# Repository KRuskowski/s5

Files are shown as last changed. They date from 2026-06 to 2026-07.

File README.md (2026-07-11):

# einheit s5 — 5-Port Managed PoE Switch (product SKU: S501)

A 5-port gigabit **managed switch with PoE PSE**, built for an industrial
DIN-rail box. An Allwinner T113-S3 runs the Linux management plane and drives a
KSZ9477 switch ASIC over the kernel DSA subsystem; the ASIC does line-rate L2
switching, and two TPS23861 controllers source PoE on all five ports. The
simplest member of the `s1xx` Linux-switch family — `s100`'s software retargeted
onto cheaper hardware.

## Where it sits in the einheit switch line

| Project | CPU | ASIC | Framework | Role |
|---|---|---|---|---|
| `s` | RP2040 (bare metal) | KSZ8795 (SPI) | `cli/core` (C11) | Tiny embedded switch, serial CLI only |
| `s100` | Linux | KSZ9567 (DSA) | full `einheit-cli` | Linux switch CLI, 7-port |
| **`s5`** | **T113-S3 (Linux)** | **KSZ9477 (DSA)** | **`einheit-cli` + PoE** | **5-port managed PoE switch** |

s5 is essentially `s100`'s software (DSA switch adapter, einheit-cli) on cheaper
T113-S3 hardware with the 5-port KSZ9477, plus PoE PSE that `s100` doesn't have.

## Hardware — two boards

Split across a **core** board and a **power** board, joined by a coplanar
**Samtec PowerStrip** board-to-board interconnect (54 V PoE bus + MAIN_EN + logic;
no cable). Both on the SKiDL → KiCad netlist flow. **Both are essentially routed.**

### Core board — `hw/core` (4-layer, ~235 parts)
The switch + front I/O. Routed: ~2000 tracks / ~500 vias + copper zones.

| Block | Part |
|---|---|
| Management SoC | Allwinner **T113-S3** (eLQFP128, SiP 128 MB DDR3 — no external DDR routing, which is what makes 4-layer viable) |
| Switch ASIC | **KSZ9477S** (128-TQFP) — 5× GbE PHY + RGMII CPU port (port 6, MAC-to-MAC, no magnetics) |
| PoE PSE | 2× **TPS23861** (4-ch each) — all 5 ports |
| Magnetics + jacks | 5× PoE magnetics (LinkPP LPJG0926HENL) + RJ45 |
| Boot flash | **W25N02JW SPI NAND** (shared SPI0 bus) |
| Misc | watchdog (TPS3823), USB-C (FEL/debug), UART console |

Detail: `hw/core/README.md`, `hw/core/T113S3_PINMAP.md`, `hw/core/BOM_REAL_PARTS.md`.

### Power board — `hw/power` (~60 parts)
Industrial **24 V DC in → PoE + logic rails**. Routed mostly as copper pours.

- **24 V → LM5122 boost → 54 V** (VBUS_54V, the PoE bus)
- **TPS54560 buck → 5 V**, then LDO chain (3.3 / 2.5 / 1.2 / 1.8 / 0.9 V)
- High-current commutation loops laid out per `hw/power/CAP_PLACEMENT.md` (the
  boost output loop and buck input loop are the layout-critical ones).

## Software (`src/`, v0.1.0)

The einheit-cli stack on the **confd/engine management plane**:
- `switch_adapter.cc` — KSZ9477 via kernel DSA (ports directly from `s100`)
- `backend.cc` / `service.cc` — the management binary
- `poe.cc` — PoE port control
- `dsa.cc`, `sys.cc`, `util.cc` — DSA + platform glue

Builds `einheit_s5` (static) + `einheit_launch`. In-process transport, **no ZMQ**
(`EINHEIT_NO_ZMQ=ON`, like s100). Web UI (einheit-ui) planned — the T113-S3 has
the headroom.

### Rootfs
SPI NAND is too small for Debian → **Buildroot/OpenWrt minimal rootfs** (squashfs
in NAND). Different image pipeline from the firewall (T527 + eMMC + Debian).

## Status

- **Software:** v0.1.0, building. Switch adapter (KSZ9477/DSA), backend/service,
  PoE control; migrated to the confd/engine management plane.
- **Hardware:** core board **routed and DRC-clean**; power routed via copper
  pours (16 zones). 3D models aligned for the enclosure. Power board being
  redone (connector change moved the outline).
- **Power-tree audit (datasheet-verified):** all rails checked against
  datasheets — VDD-CORE/VDD-SYS 0.9 V, KSZ core 1.2 V / analog 2.5 V / I/O
  3.3 V, T113 VCC-DRAM fed by internal LDOB (pin 30 → 48/49), DZQ = 240 Ω,
  both PoE controllers' A3 address straps intentional, buck EN/FB/PG correct.
  **No board-killers.**
- **Resolved decisions:** ASIC = KSZ9477 · flash = SPI NAND (W25N02JW) ·
  board interconnect = Samtec PowerStrip (replaced the cable) · mounting M2.5.

### Open hardware items
1. **KSZ analog-supply ferrite — OPEN (must-fix before fab).** AVDDH (2.5 V,
   7 pins) and AVDDL (1.2 V, 9 pins) are fed straight from the regulators with
   no ferrite. Microchip HW Design Checklist DS00004151A §3.2 requires a series
   bead per analog rail (EVB uses 220 Ω 0603, low-DCR ≤0.05 Ω/1.2 V ≤0.1 Ω/
   2.5 V, ≥400/500 mA). Omitting eats 1000BASE-T compliance margin. Needs a
   net split (AVDDH/AVDDL onto their own post-ferrite nets) + 2 beads.

### Resolved by the datasheet audit
- **Power tree** — all rails datasheet-verified, no board-killers.
- **RGMII clock** — floating `RGMII_CLKIN_25M` (PG13) is a **non-issue**: the
  T113 EMAC self-generates the 125 MHz RGMII TXC internally (`ETCS_INT_GMII`);
  PG13 is an unused optional ext-clock input, not a 25 MHz ref. Both link
  clocks (TXC KSZ48↔T113·5, RXC KSZ57↔T113·121) are routed; SYNCLKO strap +
  pull-up correct. Cleanup only: rename the misnamed `_25M` net, give PG13 a
  defined level in the DTS. (RGMII **delay** — rgmii-id / KSZ pad-skew — is the
  software gotcha to handle at bring-up.)
- **T113 exposed pad → GND** — done (pad 129 = 6.4 mm EP, grounded).
- **T113 AVCC** — netlist correct at 1.8 V (pinmap doc was wrong, fixed);
  ferrite/RC filter recommended but optional (low-current analog).
- **Unused analog rails** (VCC-LVDS/HPVCC/TVOUT/TVIN) — safe to leave unpowered.

## v1 scope

A managed 5-port gigabit PoE switch configured via CLI (and later web UI):
- Per-port: enable/disable, link status, speed/duplex, statistics, **PoE control**
- VLAN: 802.1Q port-based and tagged
- Port mirroring, MAC table view, basic STP (if KSZ9477 + DSA expose it)

Out of scope for v1: LACP/bonding, advanced QoS, SNMP, routing (that's the
firewall's job).

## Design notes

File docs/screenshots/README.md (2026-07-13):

# s5 — 3D renders

3D views of the einheit **s5** core board and its DIN-rail enclosure, captured
2026-07-13 (KiCad 3D viewer + Fusion). Roughly board views first, enclosure last.

## screenshot_1
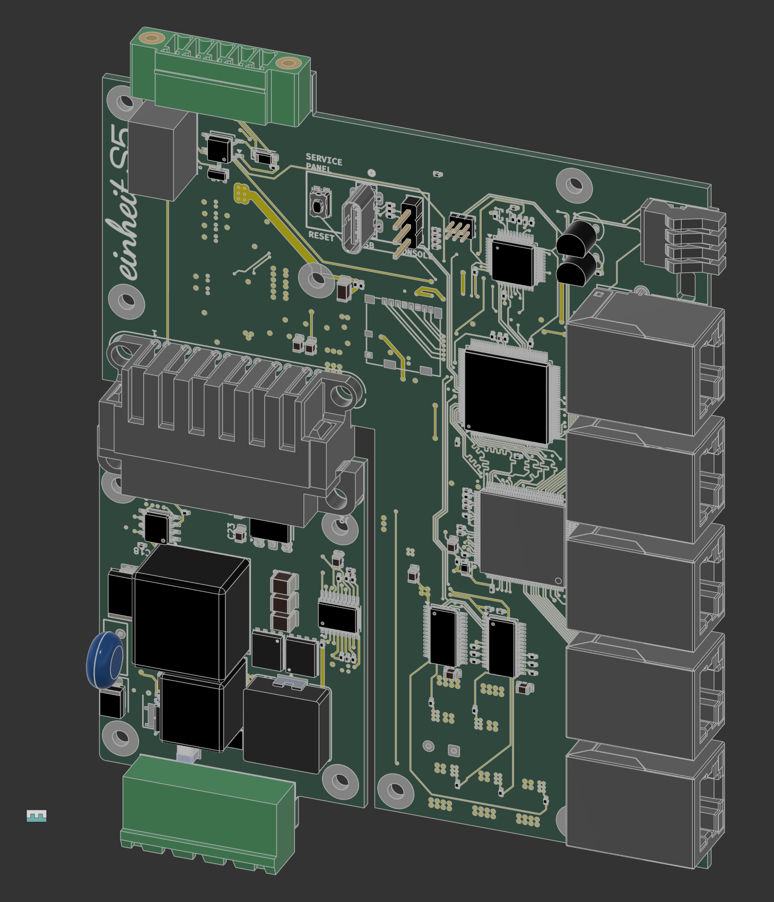
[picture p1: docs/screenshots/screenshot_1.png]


## screenshot_2
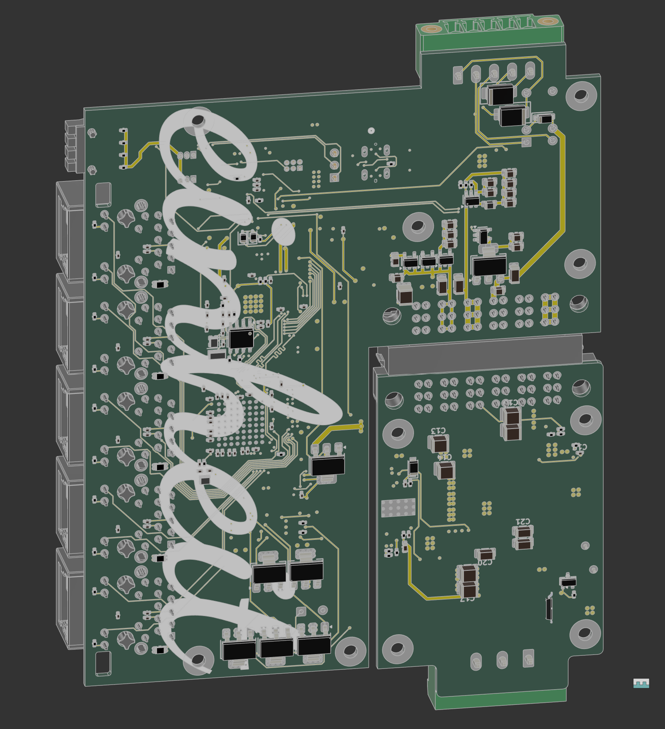
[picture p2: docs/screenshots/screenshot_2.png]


## screenshot_3
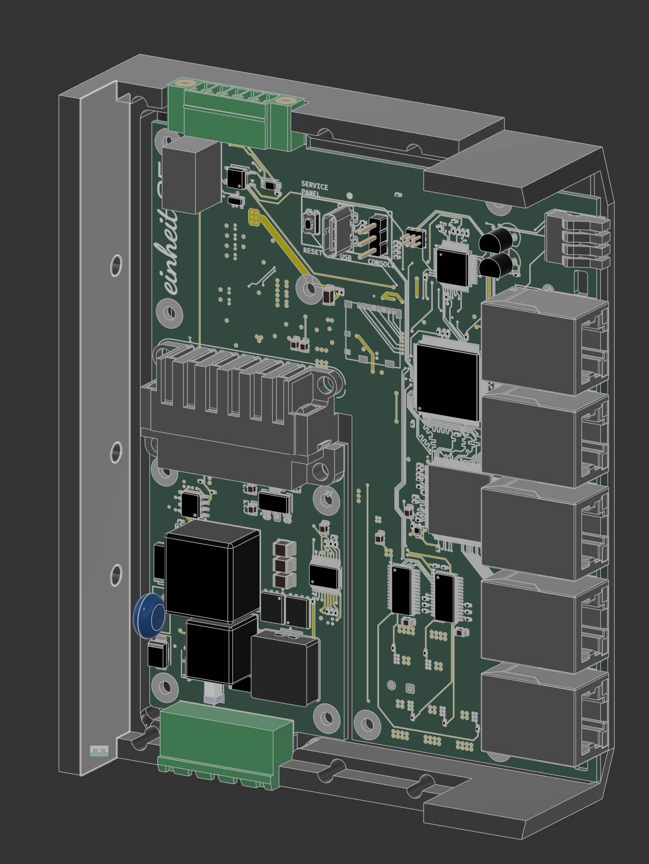
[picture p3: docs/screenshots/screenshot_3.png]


## screenshot_4
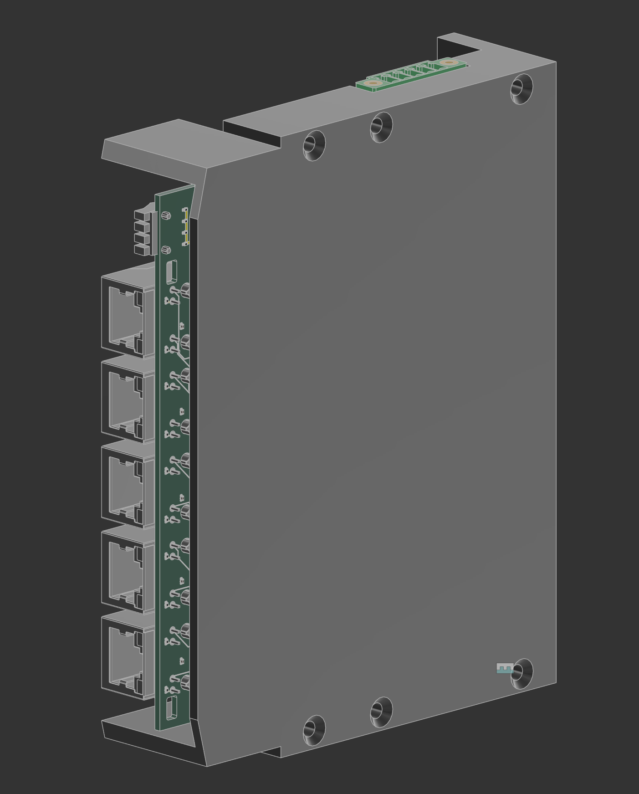
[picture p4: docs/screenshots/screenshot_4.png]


## screenshot_5
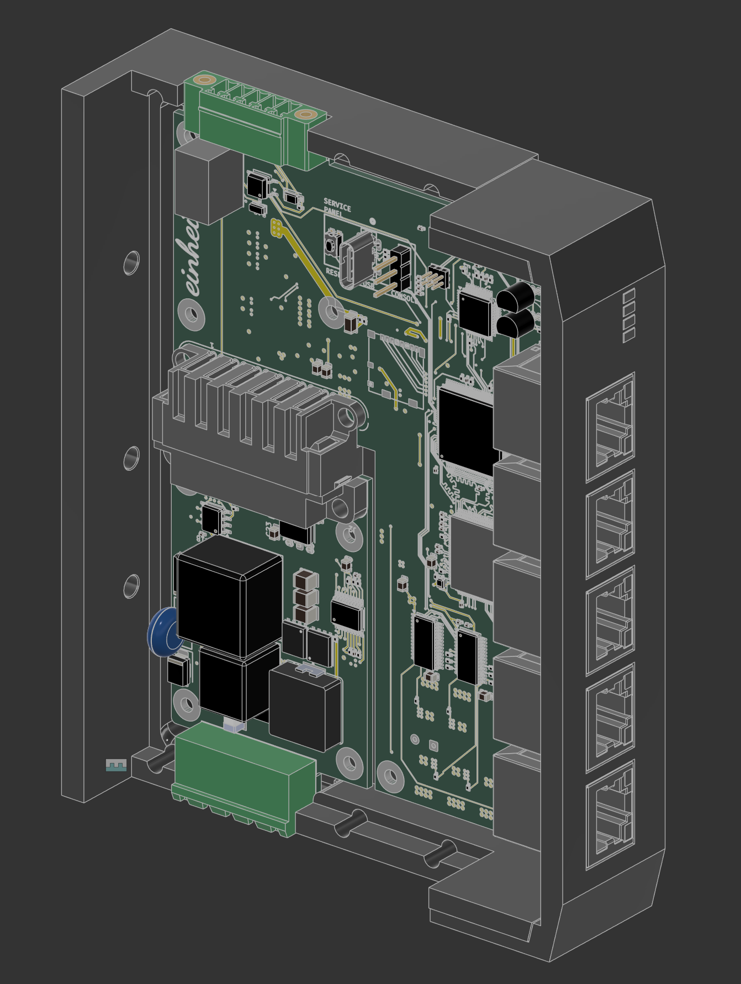
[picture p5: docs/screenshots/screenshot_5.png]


## screenshot_6
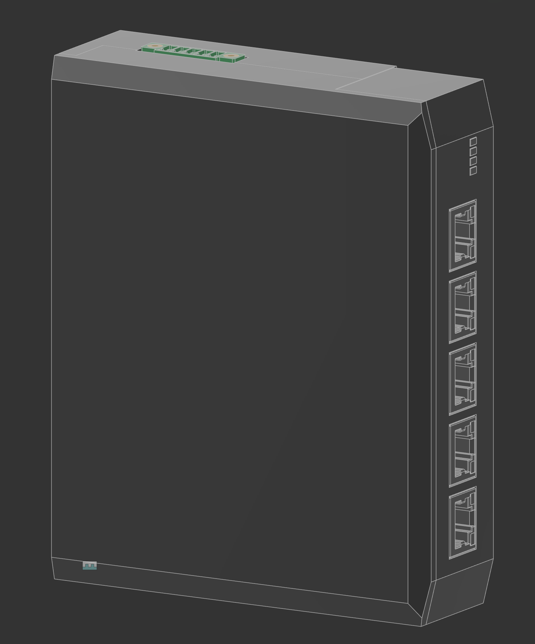
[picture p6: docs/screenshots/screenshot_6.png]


## screenshot_7
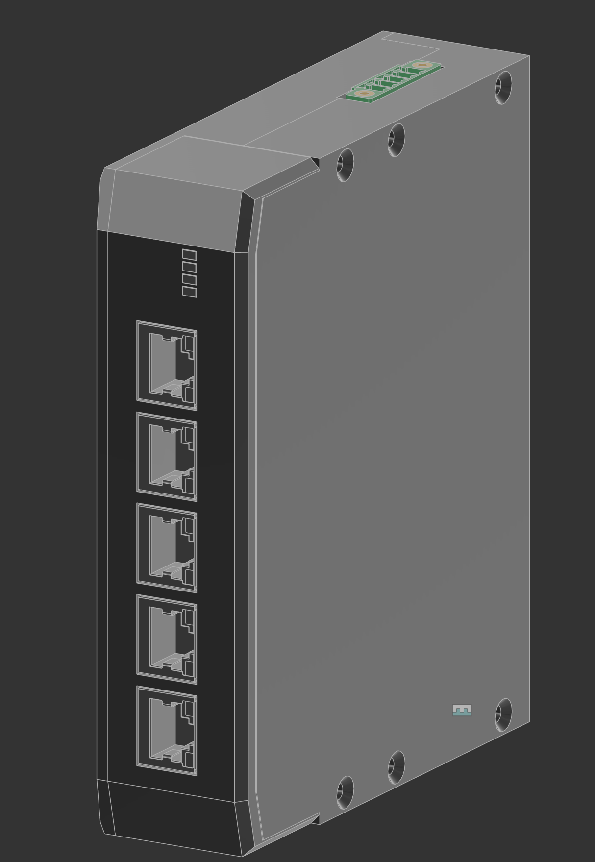
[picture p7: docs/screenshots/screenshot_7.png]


## screenshot_8
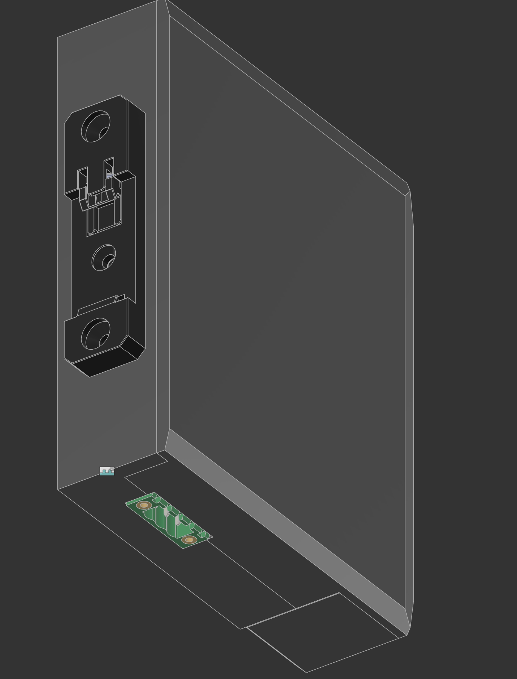
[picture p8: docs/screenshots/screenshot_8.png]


## screenshot_9
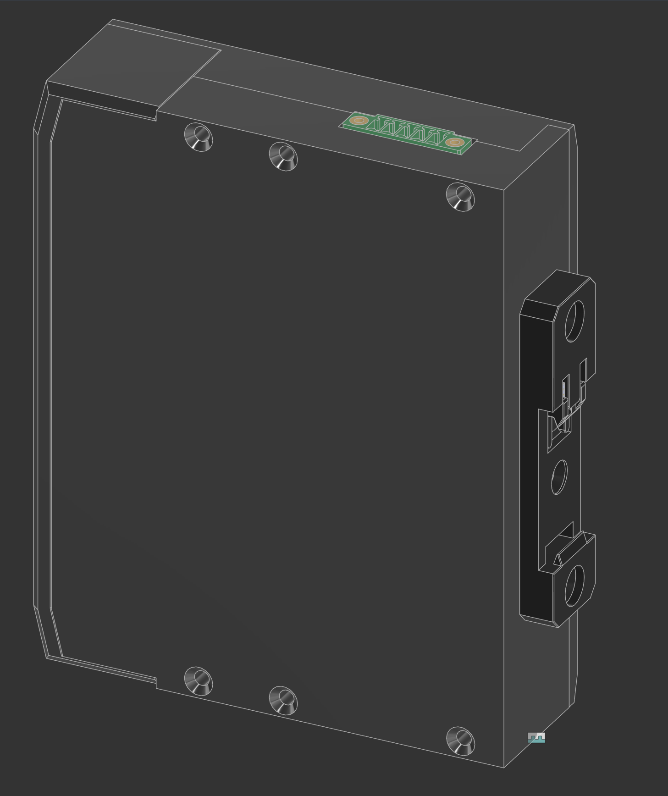
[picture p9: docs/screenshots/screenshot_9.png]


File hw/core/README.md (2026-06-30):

# s5 Hardware — 5-Port Managed Switch Board

KiCad + SKiDL hardware for the s5 (S501) switch.

## Generating the netlist

```sh
export KICAD_SYMBOL_DIR=/usr/share/kicad/symbols
export KICAD8_SYMBOL_DIR=/usr/share/kicad/symbols
python netlistscript          # writes netlist_s5.net
```

Import the result into KiCad: File -> Import -> Netlist.

## What's on the board

| Block | Part | Notes |
|---|---|---|
| Management SoC | **Allwinner T113-S3** (eLQFP128, SiP 128MB DDR3) | No external DRAM routing. Real pin numbers from datasheet v1.6 (see `T113S3_PINMAP.md`). |
| Switch ASIC | KSZ9477S (128-TQFP) | 5 copper GbE PHY ports + RGMII CPU port (port 6). Mainline DSA (`microchip,ksz9477`). |
| CPU-port link | T113 EMAC (RGMII, PG bank) -> KSZ port 6 | MAC-to-MAC, no magnetics, frees all 5 copper ports for users. |
| 5x GbE ports | Discrete GbE magnetics (YDS 30F-51NL) + plain RJ45 | Full 1000BASE-T (4 pairs/port). |
| PoE PSE | 2x TPS23861 (4ch each), all 5 ports | 48V DC in, N-FET + sense per port. |
| Power input | 48V DC -> TPS54560 buck (5V) | LDO chain: 3.3/2.5/1.2V (KSZ) + 0.9V buck (T113 core) + 1.8V LDO (DRAM). |
| Boot flash | W25Q128 SPI NOR (SOIC-8) | Shared SPI0 bus; flash CS on PC3, KSZ CS via GPIO. |
| Watchdog | TPS3823-33 (SOT-23-5) | RST -> T113 RESET, WDI from T113 GPIO. |
| Console | 3-pin UART header | T113 UART0 (PE2/PE3). |
| USB | USB-C (GCT USB4110) | Device mode for debug/FEL. |
| Stackup | **4-layer** | No external DDR3 = no high-speed signal layer needed. |

## Key design files

| File | Description |
|---|---|
| `netlistscript` | SKiDL connection script (the source of truth) |
| `netlist_s5.net` | Generated netlist (0 errors) |
| `T113S3_PINMAP.md` | T113-S3 pin map extracted from datasheet v1.6 |

## Open TODOs (marked in-script)

1. T113 eLQFP128 **exposed pad** -> GND is mandatory (only one
   dedicated GND pin: AGND=91). Add EP in the footprint.
2. RGMII CLKIN 25MHz reference source (KSZ SYNCLKO or crystal).
3. Unused analog rails (VCC-LVDS/HPVCC/TVOUT/TVIN) — confirm
   per datasheet §5.3 whether they may be left unpowered.
4. AVCC filtering (ferrite bead recommended per datasheet).
5. T113 package footprint (`eLQFP128_14x14x1.4mm`) — confirm
   or create.

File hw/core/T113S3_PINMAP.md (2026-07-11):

# T113-S3 Pin Map — verified from datasheet v1.6

Extracted from the Allwinner T113-S3 datasheet v1.6 (§4.2 Pin
Characteristics, §4.3 GPIO Multiplex Function). Package eLQFP128,
14×14×1.4 mm. Use these ball numbers for the netlist SoC block —
they are real, not placeholders.

**Critical:** only ONE dedicated ground pin (AGND = 91). The part
relies on the **exposed thermal pad = GND** for the main ground
return. The EP→GND connection is not optional.

## Power / ground / clock / reset

| Function | Signal | Ball# | Rail |
|---|---|---|---|
| Core | VDD-CORE0 / VDD-CORE1 | 116, 117 | 0.9 V (DCDC) |
| System | VDD-SYS0/1/2 | 46, 51, 81 | 3.3 V |
| IO | VCC-IO | 83 | 3.3 V |
| GPIO bank PE | VCC-PE | 34 | 3.3 V |
| GPIO bank PD | VCC-PD | 66 | 3.3 V |
| GPIO bank PG | VCC-PG | 128 | 3.3 V |
| PLL | VCC-PLL | 20 | 3.3 V |
| RTC | VCC-RTC | 26 | 3.3 V |
| DRAM I/O | VCC-DRAM0/1, VDD18-DRAM | 48, 49, 50 | 1.8 V |
| DRAM ZQ cal | DZQ | 47 | (240 Ω to GND) |
| Analog | AVCC | 89 | 1.8 V (analog; ferrite/RC filter recommended) |
| Internal LDO | LDO-IN / LDOA-OUT / LDOB-OUT | 29 / 28 / 30 | in 3.3 V, outs bypass |
| Ground | AGND | 91 | + **EP = GND** |
| 24 MHz osc | DXIN / DXOUT | 23 / 22 | DCXO |
| (ref clk out) | REFCLK-OUT | 21 | |
| 32.768 kHz | X32KIN / X32KOUT | 25 / 24 | RTC |
| Reset | RESET (I/OD) | 27 | VCC-RTC domain |
| Boot select | BOOT-SEL0 (PC4) / BOOT-SEL1 (PC5) | 17 / 16 | strap |
| NC | NC0 | 106 | leave open |

Unused analog/video rails (audio codec, TV out/in, LVDS) — HPVCC
(97), VCC-TVOUT (77), VCC-TVIN (107), VCC-LVDS (65): confirm
per-module whether they may be left unpowered when the module is
unused (most can; verify in §5.3 Recommended Operating Conditions).

## RGMII → KSZ9477 port 6 (PG group, mux Function4)

Full RGMII in one contiguous bank — this is the CPU/management link
that frees all 5 copper PHYs for users.

| RGMII signal | Pin | Ball# |
|---|---|---|
| RXCTL | PG0 | 120 |
| RXD0 | PG1 | 118 |
| RXD1 | PG2 | 119 |
| TXCK | PG3 | 121 |
| TXD0 | PG4 | 123 |
| TXD1 | PG5 | 122 |
| TXD2 | PG6 | 1 |
| TXD3 | PG7 | 2 |
| RXD2 | PG8 | 3 |
| RXD3 | PG9 | 4 |
| RXCK | PG10 | 5 |
| TXCTL | PG12 | 124 |
| CLKIN (RX clk in) | PG13 | 125 |
| MDC | PG14 | 126 |
| MDIO | PG15 | 127 |

(RMII is also available on this bank if a 100 M link is ever
preferred: PG0=CRS-DV, PG1/2=RXD0/1, PG3=TXCK, PG4/5=TXD0/1,
PG12=TXEN, PG13=RXER.)

## SPI0 → KSZ9477 management + boot flash (PC group, Function2)

| SPI0 signal | Pin | Ball# |
|---|---|---|
| CLK | PC2 | 19 |
| CS0 | PC3 | 18 |
| MOSI | PC4 | 17 |
| MISO | PC5 | 16 |
| WP | PC6 | 15 |
| HOLD | PC7 | 14 |

Shared bus: SPI0-CS0 (PC3) → boot flash. The KSZ9477 needs its own
chip-select — assign a spare GPIO (e.g. a PB or PD pin) as KSZ_CS,
same pattern as v3.

## TWI0 → TPS23861 PoE controller (PB group, Function4)

| TWI0 signal | Pin | Ball# |
|---|---|---|
| TWI0-SDA | PB2 | 86 |
| TWI0-SCK | PB3 | 85 |

## UART0 debug console (PE group, Function6)

| UART0 signal | Pin | Ball# |
|---|---|---|
| UART0-TX | PE2 | 35 |
| UART0-RX | PE3 | 33 |

## Notes for the netlist

- Footprint: reuse v3's `LQFP-128_14x14mm_P0.4mm` + add the exposed
  pad (EP → GND). Confirm body/pitch matches eLQFP128 from §7.2.
- Power tree changes from v4 (H3): drop the external DDR3 (+1.5 V
  rail) and the SY8106A DVFS buck. The T113 core is a 0.9 V DCDC
  (VDD-CORE 116/117); add a 1.8 V rail for VDD18-DRAM; reuse v4's
  3.3 V for the SYS/IO/PE/PD/PG/PLL/RTC domains.
- Source: Allwinner T113-S3 datasheet v1.6, §4.2 / §4.3.

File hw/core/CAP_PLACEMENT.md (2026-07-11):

# s5-core — decoupling / bulk cap placement guide

Where every capacitor on `s5.kicad_pcb` goes, **named**. Refs match
`netlist_s5.net` (regenerate before cross-checking: `python netlistscript`).

**The one rule:** a *decoupling* cap goes **next to the power pin it serves**,
one per pin, shortest via to the plane — not clustered at the regulator. Groups
below with many caps on one rail = **one per pin of that IC.** *Bulk* caps (the
bigger 10 µF) go at the **rail source** (converter output / interconnect blade).

Cap ref ranges are from the netlist; the KSZ-vs-T113 split on the shared 3.3 V
rail is by creation order (KSZ section builds before T113).

---

## 1. Interconnect entry — at the J9 PowerStrip blades

| Rail | Caps | Value | Place |
|---|---|---|---|
| **VBUS_54V** | **C1** | 10 µF / 1210 **≥100 V** | J9 blade 1. ⚠️ must be a 100 V part |
| VIN_24V | C2, C10 | 10 µF | J9 blade 3 |
| VDD_5V | C3, C5, C11 | 10/22 µF | J9 blade 4 / 5 V input |
| VDD_3V3 (entry) | C4, C12 | 10 µF | J9 blade 5 |

## 2. Point-of-load converters — in/out caps tight to each

| Converter | Caps | Place |
|---|---|---|
| 0.9 V buck **U11** (TLV62569) | **C6, C7** (22 µF out) · **C15, C90** (10 µF) + inductor | all four sit AT U11 (top-right strip, X≈186-192 / Y≈72), NOT at the T113. Tightest loop — Cin at VIN, SW→L→Cout small |
| U3 AP2112K-2.5 (KSZ 2.5 V) | **C13** (10 µF out) | at U3 |
| U4 AP2112K-1.2 (KSZ+T113 1.2 V) | **C14** (10 µF out) | at U4 |
| AP2112K-1.8 (T113 1.8 V) | **C8, C9, C16** (10 µF) | at the LDO |
| 3.3 V rail bulk | **C91** (10 µF) | bulk on VDD_3V3 near the LDO cluster (U3/U4/U12, X≈171/Y≈87) / where VDD_3V3 lands from J9 — not pin-critical |
| microSD VDD | **C95** (100 nF) | at **J8** microSD VDD pin (X≈175/Y≈104) — SD-card 3.3 V decoupling |
| flash VCC | **C96** (100 nF) | at **U8** W25N02 flash pin 8 VCC (X≈162/Y≈124) — tight |

## 3. KSZ9477S (U1) — one cap per power pin

| Rail | Caps | Value | Place |
|---|---|---|---|
| **VDD_1V2** (core) | **C26–C45** (20) | 100 nF | **one next to each KSZ 1.2 V pin** — the big one |
| VDD_2V5 (analog) | **C17–C25** (9) | 100 nF | one per KSZ 2.5 V (AVDDH/VDDHS) pin |
| VDD_3V3 (I/O) | **C46, C47, C48** | 100 nF | one per KSZ VDDIO pin |
| 25 MHz crystal | **C49, C50** | 15 pF | XI / XO legs, tight to the crystal |
| Reset RC | **C51** | 10 µF | at the KSZ reset pin |

## 4. T113-S3 (U7) — one cap per power pin

| Rail | Caps | Value | Place |
|---|---|---|---|
| **VDD_3V3** (I/O banks) | **C68–C79** (12) | 100 nF | one per T113 VCC-IO 3.3 V pin |
| **VDD_CORE 0.9 V** (VDD-CORE + VDD-SYS) | **C80–C85** (6) | 100 nF | one per core pin. ⚠️ VDD-SYS is 0.9 V, not 3.3 |
| VDD_1V8 (PLL/RTC/AVCC/DDR-ctrl) | **C86–C89** (4) | 100 nF | one per 1.8 V analog pin. ⚠️ not 3.3 V |
| Internal LDO out | **C66, C67** | 1 µF | at T113 LDO-A / LDO-B output pins |
| 24 MHz crystal | **C92, C93** | 18 pF | XIN / XOUT, tight to the crystal |
| Reset | **C94** | 100 nF | at the T113 reset pin |

## 5. TPS23861 PoE PSE (U11 / U12)

| Rail | Caps | Place |
|---|---|---|
| **VDD_3V3_PSE** (vpse33, always-on) | **C62, C64, C100, C101** | 2 per controller at the VDD pin (1) |
| **VBUS_54V** (VPWR) | **C63, C65** (100 nF) | near each controller's VPWR pin (28). ⚠️ 100 nF but on the 54 V rail — must be **≥100 V** parts |

## 6. Standby / PoE-logic 3.3 V (always-on)

| Rail | Caps | Place |
|---|---|---|
| VDD_3V3_SB | **C97–C99, C102–C105, C107–C109** (10) | at the standby 3V3 LDO (U18/U20) + the PoE-logic loads |

## 7. RJ45 MagJacks (J2–J6) — center-tap caps

| Port | Caps | Place |
|---|---|---|
| P1 | C52, C53 | at MagJack 1 center-tap pins (Bob-Smith) |
| P2 | C54, C55 | at MagJack 2 |
| P3 | C56, C57 | at MagJack 3 |
| P4 | C58, C59 | at MagJack 4 |
| P5 | C60, C61 | at MagJack 5 |

## 8. Misc

| Cap | Net | Place |
|---|---|---|
| C106 | MCU_NRST | watchdog / reset RC |
| C110 | PE | earth Y-cap (protective earth) |

---

## Priority order when placing

1. **0.9 V buck loop** (C6/C7/C15 + L) — fires or fails EMI if loose.
2. **VBUS_54V bulk C1** — 100 V part, right at the blade.
3. **KSZ 1.2 V (C26–C45)** and **T113 core (C80–C85) / 1.8 V (C86–C89)** — one per pin, shortest vias.
4. Everything else (2.5 V, 3.3 V decoupling, magjack CT caps) — one per pin, less critical.

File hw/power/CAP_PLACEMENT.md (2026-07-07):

# s5-power — decoupling / bulk cap placement guide

Which component each capacitor must sit next to when laying out `power.kicad_pcb`.
Refs match `netlistscript` (regenerate before cross-checking: `netlist_s5power.net`).

**Two things that bite:**

- **Several caps share the `VIN_24V` net but belong in different places** — do not cluster them. C4 bypasses the boost controller, C13/C14 feed the boost power stage, C17/C18 feed the buck input. Same net, three physical locations, each next to its own consumer.
- **The loop caps (⚠) are the ones that cause fires / fail conducted-EMI if placed loosely.** Place them first and tightest; everything else is secondary.

## ⚠ Critical high-current loops — tightest, place first

| Cap | Value | Place across / next to |
|-----|---|---|
| **C10, C11, C12** | 10µF/100V | Boost **output** loop: across **Q3 (QH) drain pins 5–8 (VBUS_54V)** and **Q2 (QL) source pins 1–3 (PGND)**. This is the boost commutation loop — keep the Cout→Q3→Q2 area physically tiny. |
| **C17, C18** | 2.2µF | Buck **input** loop: hug **U2 pin 2 (VIN)** and **U2 pin 7 + EP (pin 9, GND)**, forming a tight loop with catch diode **D3**. Single most layout-sensitive cap on the buck. |
| **C13, C14** | 22µF/63V | Boost power-stage **input reservoir** (feeds the inductor). Straddle VIN_24V→GND right at **RS pin 1** (24V side of the sense resistor, = L1's input end); ground into the **PGND pour by Q2 (QL) source**. Closes the loop C13/14→RS→L1→QL→PGND. NOT at the LM5122 chip (that's C4) and NOT at the board entry (that's C2/C3). Boost input current is continuous, so "near RS/L1, grounded to PGND" is enough — not as critical as the C10–C12 output loop. |

## LM5122 boost controller (U1) — housekeeping, hug the pin

| Cap | Value | Near |
|-----|---|---|
| **C4** | 1µF | U1 **pin 5 (VIN)** → return to pin 9 (AGND) |
| **C5** | 4.7µF | U1 **pin 17 (VCC)** → AGND |
| **C9** | 100nF | Bootstrap: U1 **pin 20 (BST)** → **pin 18 (SW)**; keep the loop to the Q2/Q3 gate area short |
| **C6** | 100nF | U1 **pin 7 (SS)** |
| **C7** | 10nF | U1 **pin 11 (COMP)** |
| **C8** | 100pF | Across U1 **pins 3/4 (CSN/CSP)** — put it right at the pins; route it and the two 100R sense resistors as a Kelvin pair back across **RS**. |

## TPS54560 buck (U2)

| Cap | Value | Near |
|-----|---|---|
| **C15** | 100nF | Bootstrap: U2 **pin 1 (BOOT)** → **pin 8 (PH)** |
| **C16** | 15nF | U2 **pin 6 (COMP)** |
| **C19, C20** | 22µF | Buck **output**: at **L2 output (VDD_5V)**; return near U2 GND |

## Input front-end & LDO

| Cap | Value | Near |
|-----|---|---|
| **C1** | 10µF | **Before** ferrite FB1 (VIN_PROT) — by Q1 drain |
| **C2** | 10µF | **After** ferrite FB1 (VIN_24V) |
| **C3** | 100µF | Bulk at input — near FB1 output / J1 |
| **C21** | 10µF | AMS1117 **U3 pin 2 (VO / VDD_3V3)** output |

## General rule

Every GND-return cap wants its own stitching via straight down to the ground plane, right at the cap pad — never a long shared ground trace back to the IC. Loop-critical caps go on the same layer as their IC, hugging the pin. Bulk caps (C3, C10–C12) may sit a little further out.

## Open item

**U3 (AMS1117) has no dedicated input cap** on pin 3 (VI / VDD_5V) — it currently relies on the buck output caps C19/C20 upstream. If U3 lands any distance from them, add a 1µF at U3 pin 3.

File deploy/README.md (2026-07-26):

# On-device deployment

What has to be installed on an s5 box beyond the binary itself, and why.
Dev-board specifics for the T153 Lume live in `t153-dev-setup.md`.

## Files

| Source | Destination | Mode | Purpose |
|---|---|---|---|
| `build/einheit_s5` | `/usr/local/bin/einheit_s5` | 755 | CLI + management plane |
| `build/einheit-launch` | `/usr/local/bin/cli` | 4755 root:root | setuid launcher (the privilege boundary) |
| `deploy/einheit-s5-boot.service` | `/etc/systemd/system/` | 644 | boot-restore (systemd images) |
| `deploy/S39einheit-s5` | `/etc/init.d/S39einheit-s5` | 755 | boot-restore (BusyBox init — the production image) |
| `deploy/factory.conf.example` | `/etc/einheit/s5/factory.conf` | 644 | shipped defaults for `load factory` |

Durable state (running config, commit history, audit log, saved
configurations, the configure-mode lock) lives in `/var/lib/einheit/s5`,
created on first run. It must be on a writable, persistent filesystem —
on the production SPI-NAND image that means a writable overlay, not
squashfs.

`/var/run/einheit` holds **generated apply artifacts** — the dnsmasq
configuration, the LLDP daemon's configuration, the mDNS repeater's
argument list, the DHCP lease database, and one marker file per service
recording whether the configuration wants it. All of it is rebuilt from
the committed configuration on every commit and every boot, so a tmpfs
is correct and a wipe is harmless. Nothing here is operator-editable and
nothing here needs to survive a reboot.

## Packages the image must carry

Phase 2 turns several features into "a daemon plus a generated config".
The backend **fails the commit** when the binary is absent rather than
reporting success and doing nothing, so a missing package is a feature
the operator cannot turn on — loudly, which is the intent. What the
image needs:

| Package | Needed by | Absent means |
|---|---|---|
| `mstpd` (+ `mstpctl`, `/sbin/bridge-stp`) | RSTP (WP1.2) | **the box cannot complete its first boot** — `stp.mode rstp` is in the shipped factory configuration |
| `dnsmasq` | DHCP server + DNS forwarder (WP2.3) | `vlans.<vid>.dhcp.*` and `dns.serve` are refused at commit |
| `mdns-repeater` | mDNS reflection (WP2.4) | `mdns.enabled` is refused at commit |
| busybox `ntpd` applet (with `-l`) | time client and server (WP2.5) | `ntp.server` is refused at commit |
| `iproute2` (`ip`, `bridge`) | fabric, VLANs, SVIs, routes | nothing works |
| `ethtool` | port speed/duplex/flow control | those paths fail; the rest is fine |

Buildroot has packages for all of these (`BR2_PACKAGE_MSTPD`,
`BR2_PACKAGE_DNSMASQ`, `BR2_PACKAGE_MDNS_REPEATER`,
`BR2_BUSYBOX_...NTPD`). mstpd is **not** in Debian trixie, so the test
VM builds it from `github.com/mstpd/mstpd` — see the note in
`test/vm_prep.sh`'s companion documentation below.

The LLDP daemon is not a package: it is `einheit_s5 --lldp-daemon`, the
same binary in another mode (see `include/einheit/s5/lldp.h` for why we
own the implementation rather than packaging lldpd). It is started by a
commit and should also be started at boot, after `--apply-boot` has
generated its configuration.

### mstpd and the kernel's user-space STP handshake

`stp.mode rstp` sets `/sys/class/net/br0/bridge/stp_state`, which makes
the kernel run `/sbin/bridge-stp br0 start`. That helper — shipped with
mstpd — starts the daemon and registers the bridge, and only if it
succeeds does the kernel settle on `BR_USER_STP` (stp_state **2**). If
the helper is missing or fails, the kernel silently falls back to its
own 802.1D (stp_state 1), which is not what the operator asked for, so
the backend verifies the resulting state and fails the commit otherwise.
`/etc/bridge-stp.conf` needs no entry: with `MSTP_BRIDGES` empty, mstpd
manages every bridge, which is what we want on a box with one.

## Boot-restore

Nothing else re-applies committed configuration when the box comes back.
Install one of the two units and the box boots into its own
configuration; install neither and every reboot is effectively a factory
reset with the operator's intent left behind in `show commits`.

```sh
# systemd
systemctl enable einheit-s5-boot.service

# BusyBox init — S39 runs immediately before Buildroot's S40network, so
# br0 and the enslaved ports exist before anything addresses br0.
chmod 755 /etc/init.d/S39einheit-s5
```

Both run `einheit_s5 --apply-boot`, which:

1. builds the switch fabric — `br0` with `vlan_filtering=1`, `lan1..lan4`
   enslaved, `lan5` left routed as the uplink, the DSA conduit up —
   idempotently;
2. re-applies the newest commit's configuration through the same
   `S5Backend::Apply` a `commit` uses;
3. reconciles: intent wins for every path the commit carried, the box
   fills in the rest.

An unconfirmed `commit confirmed` window is **reverted**, not carried
forward: the oneshot has no live timer to fire the auto-revert later, so
carrying the window would quietly make an unconfirmed configuration
permanent. Boot is the confirm deadline.

Both are ordered **before sshd and getty**, not merely before
`multi-user.target`: ordering against a target does not order against the
units pulled into it, so without naming sshd explicitly systemd starts it
concurrently and an operator can log into a switch that has no bridge and
no VLANs yet. On BusyBox init the `S39` prefix gives the same guarantee
against Buildroot's `S50sshd`.

The systemd unit is deliberately **not** ordered before
`network-pre.target`. That reads like the right thing ("before anything
touches the interfaces") and is a trap: `network-pre` is a sysinit-phase
target while the unit is `WantedBy=multi-user.target`, which systemd
reaches only after sysinit — an ordering cycle. systemd breaks a cycle by
deleting a job, and it picked this unit on 2 of 50 power cuts during
Phase 0 testing, booting the box with no fabric and no restored config,
silently. If boot-restore ever appears to be skipped, that is the first
thing to check:

```sh
journalctl -b | grep -E "ordering cycle|deleted to break"
systemd-analyze verify /etc/systemd/system/einheit-s5-boot.service
```

Exit code 0 means restored (or "nothing committed yet"); non-zero means
the fabric or the apply failed, and the box is running whatever it
powered on with. Check `journalctl -u einheit-s5-boot` or the console,
then `show fabric` and `show commits`.

There is deliberately no retry: re-running a half-applied hardware write
is how a bad boot becomes a bad box.

### Ordering caveat

DSA user ports appear asynchronously as the switch driver probes. If
`--apply-boot` runs before a port exists, the fabric bootstrap skips it
and reports it as absent rather than failing — `show fabric` names the
absent ports, and the next commit enslaves them. On an image where this
races, order the unit after the driver's udev settle.

## Verifying a deployment

```
show fabric        # bridge up, vlan_filtering yes, 4 members enslaved
show commits       # history survived the reboot
show config        # running config matches the newest commit
show status        # lock_holder=<none> on a fresh boot
```

`test/vm_integration.sh` drives all of this over ssh against a
disposable target, including power-cycling the fabric behind confd's
back and re-running `--apply-boot`.

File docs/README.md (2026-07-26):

# einheit s5 — operator documentation

Two kinds of pages, with different rules:

- **`reference.md` — generated, never hand-edited.** Produced by `einheit_s5 --dump-docs` from the schema and command tree the binary actually runs, so it cannot disagree with the product. A ctest diffs the checked-in file against the binary's output: adding a config path or verb without regenerating fails the build (`./build/einheit_s5 --dump-docs > docs/reference.md`). To fix wording here, edit the schema help strings / command specs and regenerate — that same text is what `?`, `show schema` and the hint system display.
- **`guide/` — hand-written.** The narrative that cannot be generated: what the configuration model is, how commit-confirmed saves you, how VLANs are meant to be used. Review passes and corrections belong here (and in the schema help strings via the rule above).
  - [`guide/configuration.md`](guide/configuration.md) — candidate/commit, rollback, saved configurations, boot behaviour.
  - [`guide/switching.md`](guide/switching.md) — the fabric, VLANs, ports, spanning tree, LLDP, MAC table, multicast, PoE.
  - [`guide/services.md`](guide/services.md) — SVIs, routing, DHCP, DNS, mDNS reflection, time, and what a service that is down looks like.

Every feature lands with both halves: regenerated reference plus its guide section (workspace acceptance criteria enforce this).

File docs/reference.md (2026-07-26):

# einheit S5 — CLI Reference

Generated by `--dump-docs` from the running binary (product `s5`, version 0.2.1). **Do not edit** — wording fixes belong in the schema help strings and command specs; regenerate and commit.

## Configuration paths

Set inside a `configure` session: `set <path> <value>`, `delete <path>`, then `commit`. `<name>` marks a key you choose (a port, an interface, a VLAN id).

| Path | Type | Default | Description |
|---|---|---|---|
| `dns.local_domain` | string | — | Domain for names the switch serves itself |
| `dns.primary` | ip | — | Primary DNS nameserver |
| `dns.secondary` | ip | — | Secondary DNS nameserver |
| `dns.serve` | boolean | false | Answer DNS queries from clients, forwarding what we do not know |
| `hostname` | string | — | Switch hostname |
| `igmp_snooping.enabled` | boolean | true | Prune multicast to ports that asked for it |
| `igmp_snooping.querier` | boolean | false | Send IGMP queries (needed with no router on the L2) |
| `interfaces.<name>.address` | cidr | — | Static address + prefix |
| `interfaces.<name>.dhcp` | boolean | false | Acquire the address via DHCP instead |
| `interfaces.<name>.gateway` | ip | — | Default gateway reached through this interface |
| `lldp.enabled` | boolean | true | Announce this switch to its neighbours, and record theirs |
| `lldp.port.<name>.enabled` | boolean | true | Run LLDP on this port |
| `lldp.tx_interval` | integer [5..3600] | 30 | Seconds between announcements |
| `mac.aging_time` | integer [10..1000000] | 300 | Seconds before a learned MAC is forgotten |
| `mac.static.<name>.port` | string | — | Port the static entry points at |
| `mac.static.<name>.vlan` | integer [1..4094] | 1 | VLAN the static entry belongs to |
| `mdns.enabled` | boolean | false | Repeat mDNS between VLANs so discovery crosses them |
| `mdns.reflect.<name>` | boolean | — | Include this VLAN in mDNS reflection |
| `ntp.serve` | boolean | false | Also answer time queries from clients on this network |
| `ntp.server` | string | — | NTP server hostname or IP |
| `poe.<name>.enabled` | boolean | true | PoE power delivery on this port (1-5) |
| `poe.<name>.power_limit_mw` | integer [0..30000] | — | Per-port power limit in milliwatts |
| `ports.<name>.duplex` | enum {auto, half, full} | auto | Duplex mode, or auto-negotiate |
| `ports.<name>.enabled` | boolean | true | Administrative port state (lan1..lan5, wan) |
| `ports.<name>.flow_control` | boolean | false | 802.3x pause frames |
| `ports.<name>.mtu` | integer [1280..9216] | 1500 | Maximum transmission unit |
| `ports.<name>.speed` | enum {auto, 10, 100, 1000} | auto | Link speed in Mbit/s, or auto-negotiate |
| `ports.<name>.stp.bpdu_guard` | boolean | false | Block this port if another switch sends spanning-tree into it |
| `ports.<name>.stp.cost` | integer [0..200000000] | 0 | Spanning-tree path cost; 0 derives it from link speed |
| `ports.<name>.stp.edge` | boolean | false | Access port: skip the listening delay and forward at once |
| `ports.<name>.stp.priority` | enum {0, 16, 32, 48, 64, 80, 96, 112, 128, 144, 160, 176, 192, 208, 224, 240} | 128 | Port priority; breaks ties between equal-cost paths to the root |
| `ports.<name>.vlan.<name>` | enum {tagged, untagged, pvid, untagged-pvid} | — | 802.1Q membership mode for this VID |
| `routing.enabled` | boolean | false | Forward traffic between VLANs and to the uplink |
| `routing.static.<name>.prefix` | cidr | — | Destination network; 0.0.0.0/0 is the default route |
| `routing.static.<name>.via` | ip | — | Next-hop address |
| `stp.forward_delay` | integer [4..30] | 15 | Seconds a port waits before forwarding (classic mode only) |
| `stp.hello` | integer [1..10] | 2 | Seconds between spanning-tree messages from the root |
| `stp.max_age` | integer [6..40] | 20 | Seconds before a silent neighbour is assumed gone |
| `stp.mode` | enum {rstp, stp, off} | rstp | Loop protection: rapid spanning tree, classic, or none |
| `stp.priority` | enum {0, 4096, 8192, 12288, 16384, 20480, 24576, 28672, 32768, 36864, 40960, 45056, 49152, 53248, 57344, 61440} | 32768 | Bridge priority; the lowest value on the network becomes the root |
| `vlans.<name>.address` | cidr | — | Switch address in this VLAN; giving one makes it routable |
| `vlans.<name>.dhcp.dns` | ip | — | Nameserver told to clients; defaults to the switch itself |
| `vlans.<name>.dhcp.enabled` | boolean | false | Hand out addresses to clients in this VLAN |
| `vlans.<name>.dhcp.gateway` | ip | — | Router told to clients; defaults to the switch itself |
| `vlans.<name>.dhcp.lease_time` | integer [2..10080] | 720 | Minutes a client keeps its address |
| `vlans.<name>.dhcp.range_end` | ip | — | Last address handed out |
| `vlans.<name>.dhcp.range_start` | ip | — | First address handed out |
| `vlans.<name>.dhcp.static.<name>.ip` | ip | — | Address always given to this MAC |
| `vlans.<name>.name` | string | — | What this VLAN is for, e.g. office or guest |

## Configuration lifecycle commands

| Command | Role | Description |
|---|---|---|
| `commit` | admin | Apply the candidate configuration |
| `commit confirmed <minutes>` | admin | Apply, then auto-revert unless confirmed in time |
| `configure` | admin | Enter configure mode and open a candidate session |
| `configure force` | admin | Take configure mode from another session, discarding its candidate |
| `confirm` | admin | Confirm a pending commit-confirmed (cancel auto-revert) |
| `delete <path>` | admin | Remove a candidate-config value at a schema path |
| `load factory` | admin | Load the shipped factory defaults into the candidate (commit to complete a factory reset) |
| `load merge <name>` | admin | Merge a saved configuration into the candidate |
| `load replace <name>` | admin | Replace the candidate with a saved configuration |
| `rollback candidate` | admin | Discard the candidate session |
| `rollback previous` | admin | Roll back to the previous commit |
| `rollback rescue` | admin | Restore the saved rescue configuration and commit it |
| `rollback to <id>` | admin | Re-apply a specific committed revision |
| `save <name>` | admin | Save the running configuration to a named file |
| `set <path> <value>` | admin | Set a candidate-config value at a schema path |
| `show commit <id>` | any | Show a single commit by id |
| `show commits` | any | List commit history |
| `show config [prefix]` | any | Show running configuration (optional prefix) |
| `show configs` | any | List saved configuration files |
| `show diff` | any | Show uncommitted candidate changes vs running (Junos: show \| compare) |
| `show schema` | any | List every configurable path with type + help |

## Show commands

| Command | Role | Description |
|---|---|---|
| `show counters [port]` | any | Show port counters |
| `show dhcp leases` | any | Show which clients hold which addresses |
| `show dhcp server` | any | Show the DHCP pools being served, and their usage |
| `show dns` | any | Show DNS servers |
| `show env` | any | Show terminal caps, active theme, aliases, target, session |
| `show fabric` | any | Show the switch fabric (bridge, members, conduit) |
| `show igmp-snooping` | any | Show multicast snooping state and groups |
| `show interfaces [port]` | any | Show port status |
| `show interfaces detail [port]` | any | Show configured vs negotiated link parameters and counters |
| `show ip` | any | Show IP addresses |
| `show log [lines]` | any | Show syslog |
| `show mac-table [port]` | any | Show the MAC table (static and learned) |
| `show neighbors [port]` | any | Show LLDP neighbours heard on each port |
| `show ntp` | any | Show NTP status |
| `show poe [port]` | any | Show PoE status |
| `show route` | any | Show the routing table and whether forwarding is on |
| `show spanning-tree` | any | Show the spanning tree: root, and each port's role and state |
| `show spanning-tree statistics [port]` | any | Show per-port BPDU counters and state transitions |
| `show status` | any | Show config-plane status: commits, session, edit lock, pending commit-confirmed |
| `show system` | any | Show system info |
| `show system boot` | any | Show what the last boot-restore did |
| `show system services` | any | Show the background services the switch runs, and whether they are up |
| `show users` | any | Show user accounts |
| `show version` | any | Show switch information |
| `show vlans` | any | Show VLANs: name, switch address, and member ports |

## Operational commands

| Command | Role | Description |
|---|---|---|
| `alias` | any | List aliases; `alias <name> <expansion...>` to define, `alias delete <name>` to remove. Persists to ~/.einheit/aliases.yaml. |
| `clear counters [port]` | admin | Zero the counter baseline (all ports, or one) |
| `clear dhcp lease <client>` | admin | Return one client's address to the pool |
| `clear mac-table [port]` | admin | Flush learned MACs; static entries are config and stay |
| `clear spanning-tree bpdu-guard <port>` | admin | Return a port the BPDU guard blocked to service |
| `clear spanning-tree statistics [port]` | admin | Zero the spanning-tree counter baseline |
| `daemon start` | admin | Start the daemon via systemd (local only) |
| `daemon status` | any | Show the service's systemd status (local only) |
| `doctor` | any | Run framework health checks (transport, schema, theme, keys) |
| `exit` | any | Exit the shell |
| `explain` | any | Show the wire representation + role + session requirement for a command |
| `help` | any | Show help for a command or topic |
| `history` | any | Show the current user's command history |
| `logs` | any | Print daemon logs; use `logs --follow` |
| `macro delete` | any | Remove a saved macro |
| `macro end` | any | Stop recording the current macro |
| `macro list` | any | List saved macros |
| `macro record` | any | Start recording a macro; `macro end` stops |
| `macro run` | any | Replay a saved macro by name |
| `macro show` | any | Show the commands in a saved macro |
| `ping <host>` | any | Ping a host |
| `poe reset <port>` | admin | Power-cycle a PoE port |
| `quit` | any | Exit the shell |
| `reboot` | admin | Reboot the system |
| `shell` | admin | Drop to a POSIX shell (audit-logged) |
| `statusbar` | any | Toggle the status chips line above the prompt: `statusbar on\|off` |
| `theme list` | any | List shipped named themes |
| `theme use` | any | Switch to a named theme for the remainder of this session |
| `traceroute <host>` | any | Trace route to host |
| `user add <name> <role>` | admin | Add or update a user |
| `user remove <name>` | admin | Remove a user |
| `watch` | any | Re-run a show command on event |

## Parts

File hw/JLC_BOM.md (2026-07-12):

# s5 — JLCPCB assembly cross-reference (both boards)

Cross-referenced against the JLC/LCSC assembly library on **2026-07-12**.
**Stock is point-in-time — re-confirm every C# in the JLC cart before ordering.**
Selection rule (per Karl): availability/longevity first, cost second.

**LCSC# for every named part is now set as an `LCSC` field in both netlist
scripts** (core: 38 parts, power: 11), so the Fabrication Toolkit BOM
auto-populates on import. Jellybean R/C/L carry no C# → JLC Basic auto-match by
value. Blank named parts = the hand-add pile (Osram LEDs, Samtec/Phoenix, USB-C,
L1/F1 on the power board).

Two buckets: **JLC must place** (fine-pitch / leadless — infeasible by hand) and
**hand-add** (connectors, magnetics, THT — Karl self-sources & solders).

---

## Silent killers — RESOLVED (all four fixed in the netlist)

| Item | Board | Resolution |
|---|---|---|
| **Flash U8** | core | Was `SOIC-8` (wrong — W25N02JW is only WSON-8 8×6). Now **W25N02KWZEIR (C17401814)**, 1.8 V, in-stock; footprint imported from the JLC part → `chips:WSON-8_L8.0-W6.0-P1.27-TL-EP-1`, EP→GND. **U8 needs re-place + reroute** (WSON ≠ SOIC). |
| **PMEG10010 D4** | power | Footprint → `Nexperia_CFP3_SOD-123W` (correct package). |
| **Q1–Q5 PoE FET** | core | Was generic 30 V placeholder — **wrong, they sit on the 54 V PoE bus.** Now **DMN10H220LE-TP** (100 V / 80 mΩ, avalanche-rated, SOT-223, no footprint change), **C50314242** verified stocked. |
| **Osram M676 LEDs D3–D6** | core | **Kept — the 1278.1004 light guide requires Osram Mini-TOPLED.** Hand-soldered, mark do-not-place for JLC. No substitutes. |

---

## CORE board

### JLC must place (SMT — don't hand-solder)

| Ref | Part | LCSC# | Lib | Note |
|---|---|---|---|---|
| U1 | KSZ9477STXI | **C631685** | Ext | stock ~26 — pre-order |
| U7 | T113-S3 | **C5197687** | Ext | in library ✓ (~2758) |
| U9,U13 | TPS23861PW | **C2872514** | Ext | OOS at LCSC; need ×6 — pre-order |
| U11 | TLV62569PDDCR | **C398365** | Ext | clean |
| U19 | STM32G071CBT6 | **C432212** | Ext | clean |
| U8 | W25N02KWZEIR | **C17401814** | Ext | WSON-8 8×6, in stock; reroute needed |
| U10 | TPS3823-33DBVR | **C7719** | Ext | clean |
| U18,U20 | TPS7B6933QDCYRQ1 | **C108471** | Ext | verified ✓ |
| U3 | AP2112K-2.5 | **C176945** | Ext | stock ~230 |
| U4 | AP2112K-1.2 | **C460310** | Ext | clean |
| U12 | AP2112K-1.8 | **C176944** | Ext | clean |
| U17 | SHT40-AD1B-R3 | **C2848306** | Ext | DFN, confirm stock |
| U21 | EL357N(C) | **C29981** | Basic | confirm live stock |
| D54,D56 | 1N4148W (SOD-123) | **C81598** | Basic | huge stock ✓ |
| D2 | 1N4148 (SOD-323) | **C2128** | Basic | LCSC OOS → alt C9900014362 |
| D52,D53 | BAT54 (SOD-323) | **C22629** | Ext | no Basic in SOD-323 |
| D55,D57 | SMBJ33CA (SMB) | **C83325** | Ext | |
| FB1,FB2 | Ferrite 220Ω@100MHz (Murata BLM18SG221) | **C88988** | Pref | **use this, not a JLC-Basic ferrite** (those are ~200 mA/380 mΩ = fail spec). Alt TDK C76815 |
| Y1 | 25 MHz xtal (NDK NX2016SA) | **C843258** | Pref | stock ~15 — pre-order/alt |
| Y2 | 24 MHz xtal | **C2682776** | Pref | clean |
| Y3 | 32.768 kHz xtal | **C97606** | Pref | 12.5 pF; lower-CL sib C97605/C97604 |
| Q60 | 2N7002 | **C8545** | Basic | std-threshold — use 2N7002K if driven at 3.3 V |
| Q1–Q5 | PoE pass FET **DMN10H220LE-TP** (100 V / 80 mΩ) | **C50314242** ✓ | Ext | verified stocked; LCSC field set in netlist |
| SW2 | tactile KMR231GLFS | **C99271** | Basic | optional-JLC |
| J8 | microSD 104031-0811 | **C585350** | Ext | optional-JLC |

### Hand-add (Karl self-sources)

| Ref | Part | Note |
|---|---|---|
| J9 | Samtec MPT-06-01 PowerStrip | LCSC-catalog only (C3684105), THT — not assemblable |
| J11 | Phoenix MC 1,5/5-GF-3,5 | THT, not in placement lib |
| J12 | Molex USB-C 2171820001 | not in LCSC/JLC at all; sibling 2171800001 = C3197940 if you want JLC to place |
| J2–J6 | LinkPP LPJG0926HENL magjacks | JLC *can* wave-solder (C2874230, Ext) if desired; otherwise hand |
| U15,U16 | DS18B20 (TO-92) | THT; SMT alt = DS18B20Z SOIC-8 **C97190** for a clean line |
| K1 | Hongfa HFD23-024-1ZS relay | **C32381** (THT; BOM's old C190593 was wrong). OOS at check |
| D3–D6 | Osram M676 LEDs | not in JLC (footprint issue above) |
| J7,J10 | pin headers (2.54 / 1.27 SWD) | J7=C49257; J10 1.27 2x3 SMD SKU unverified |
| LP1, MH1–6, TS1 | light guide / mounts / thermostat | mechanical, not placed |

---

## POWER board

### JLC must place (SMT)

| Ref | Part | LCSC# | Lib | Note |
|---|---|---|---|---|
| U1 | LM5122MHX | **C77241** | Ext | HTSSOP-20-EP |
| U2 | TPS54560DDAR | **C31966** | Ext | SOIC-8-EP |
| U3 | AMS1117-3.3 | **C6186** | **Basic** | only Basic part on this board |
| Q2,Q3 | BSC057N08NS3G | **C534354** | Ext | PowerPAK SO-8, 80 V |
| Q1 | SQJ409EP | **C727776** | Ext | verified ✓ PowerPAK SO-8L |
| D2 | BZX84C12 | **C112551** | Ext | |
| D4 | PMEG10010ELR-QX | **C5361358** | Ext | footprint → SOD-123W (fixed) |
| D1 | SMBJ33A (SMB) | **C78419** | Ext | |
| D3 | SS56 (SMC) | **C2848695** | Ext | note SS56 is often SMA; this is the SMC listing |
| FB1 | Coilcraft XAL1010-222MED | **C5125746** | Ext | verified ✓; stock ~287 — pre-order |

### Needs a decision / hand-add

| Ref | Part | Note |
|---|---|---|
| L1 | Bourns SRP1245A-220M | **not in JLC** → swap to SRP1265A-220M **C2041465** (bigger 13.5×12.5 footprint) or hand-solder |
| F1 | Littelfuse 0452012 (Slo-Blo 12 A) | **not in JLC** → hand-solder, or fast-acting 0451012 **C99549** (changes inrush) |
| RV1 | MOV S14K30 | **DNP** (JLC skips); THT if ever populated (C210626) |
| J2 | Samtec MPS-06-01 PowerStrip | not in lib, THT — hand-solder |
| J1 | Phoenix MSTB 2,5/3-GF-5,08 | not in lib, THT — hand-solder |
| MH1–4 | M2.5 mounts | mechanical |

---

## Order-time checklist
1. **Fix the 3 footprints** (flash, PMEG, LEDs) or move those parts to hand-add.
2. **Pick Q1–Q5** (DMN3032LE-13 C156338) in the netlist.
3. **Pre-order thin stock:** KSZ (26), TPS23861 (OOS), W25N02 (OOS), AP2112K-2.5 (230), 25 MHz xtal (15), XAL1010 (287).
4. **Ferrites = C88988** (not a Basic ferrite).
5. Budget **per-feeder Extended fees** — almost the whole BOM is Extended; only AMS1117, a few diodes, 2N7002, EL357N, KMR2 button are Basic.
6. Everything in the hand-add tables: self-source & solder as planned.

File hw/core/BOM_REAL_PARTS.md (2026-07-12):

# s5 — Real-parts BOM (JLCPCB assembly)

Selection rule (per Karl): **availability/longevity first, cost second.**
Committed parts (ICs, LDOs, connectors, specific-footprint FETs, relay, opto)
= name-brand + AEC-Q where possible, stocked on **JLC and Digikey/Mouser**.
Jellybean passives = JLC Basic, interchangeable (EOL risk ≈ 0).

Status legend: ✅ confirmed on JLC · 🔎 verify C# / live stock on JLC · ✏️ needs footprint download · ⚠️ design decision below.

## Committed actives / ICs
| Ref | Function | Recommended part | LCSC | Package | Notes |
|-----|---|---|---|---|---|
| U18 | standby 3V3 LDO (24→3.3V) | **TI TPS7B6933QDCYRQ1** | C108471 | SOT-223-4 | ✅ AEC-Q100, 40V, 150mA, low-Iq. No EN (always-on). |
| U20 | PoE-logic 3V3 LDO (24→3.3V) | **TI TPS7B6933QDCYRQ1** | C108471 | SOT-223-4 | ✅ same P/N as U18. ⚠️ PoE-shed moves to PSE SHTDWN (see notes) so no EN needed. |
| Q50 | reverse-polarity P-FET | **Infineon BSP315P** (alt onsemi NVF2955) | 🔎 | SOT-223 | -60V, ~55mΩ. Matches current footprint. |
| Q60 | relay-coil driver | **2N7002** (Nexperia/onsemi) | JLC Basic | SOT-23 | logic-level, 60V/300mA; coil is ~6mA. |
| U21 | DI opto-isolator | **EL357N(C)** or LTV-357T | JLC Basic | SOP-4 (SMD) | ✏️ was PC817 DIP — use SMD for JLC. |
| K1 | fault relay | **Hongfa HFD23-024-1ZS** | C32381 | THT, 1 Form-C | 24V coil, 2A. ⚠️ THROUGH-HOLE (JLC selective/hand solder) + was OOS at check. Prior C190593 was the WRONG part (HFD4/24-S). Matches netlist Relay_HFD23_1C_THT. |
| U10 | STM watchdog | TI **TPS3823-33** | 🔎 | SOT-23-5 | already real. |
| U15/U16 | temp sensors | ADI **DS18B20** | 🔎 | TO-92 or SOIC-8 | already real. Pick SMD (SOIC) for JLC if hot-spot allows. |
| U17 | humidity | Sensirion **SHT40-AD1B** | 🔎 | DFN-4 | already real (extended). |
| U19 | supervisor MCU | ST **STM32G071CBT6** | 🔎 | LQFP-48 | already real. |
| (U1/U6/U8/U9/U11/U12/U14/U7) | KSZ9477 / TPS54560 / W25N02JW / TPS23861 / TLV62569 / AP2112 / LM5122 / T113-S3 | already real MPNs | 🔎 | — | verify each is JLC-stocked (some may be hand-add). |

## Connectors
| Ref | Function | Recommended part | LCSC | Notes |
|-----|---|---|---|---|
| J1 | power in (bottom) | Phoenix **MSTB 2,5/3-GF-5,08** | 🔎✏️ | industrial standard; may be JLC hand-add (THT). |
| J11 | signal (top) | Phoenix **MC 1,5/5-GF-3.5** | 🔎✏️ | 3.5mm — can't cross-plug with power. |
| J8 | microSD (non-edge) | **Molex 5033981892** (push-push) | C428492 | ✅ self-contained, not edge. ✏️ swap from 104031, remap pads. |
| J_USB | USB-C (vertical, internal) | **vertical 16P USB-C** | C9900273287 | ✅ upright, USB2. ✏️ swap from horizontal GCT, remap pads. |
| J2–J6 | 5× RJ45 PoE (front) | **LinkPP LPJG0926HENL** | 🔎 | already chosen. |
| J10 | SWD header | 2×3 1.27mm | JLC Basic | internal. |

## Protection / passives
| Ref | Function | Recommended | Notes |
|-----|---|---|---|
| F1 | input fuse | 2A slow-blow 1206 (Bel/Littelfuse) | 🔎 or PPTC. |
| RV1 | MOV | ⚠️ **DNP** unless cert demands — the TVS covers normal surge at 24V. |
| RT1 | inrush NTC | ⚠️ likely **DELETE** — TPS54560/LM5122 soft-start, 24V inrush is modest. |
| FB1 | ferrite bead | Sunlord/Murata 1206, 600Ω@100MHz, ≥2A | JLC Basic. |
| D50 | VIN TVS (uni) | **SMBJ30A** (28.9V standoff, clamps <48V) | JLC. |
| D55/D57 | signal TVS (bidir) | **SMBJ33CA** | JLC. |
| D51 | Vgs clamp zener | **BZX84C12** | JLC Basic. |
| D54/D56 | flyback/reverse | **1N4148W** (SOD-123) | JLC Basic. |
| D52/D53 | watchdog Schottky | **BAT54** | JLC Basic. |
| TS1 | over-temp thermal switch | **KSD9700-class, ~70°C NO** | ⚠️ mechanical/THT — likely hand-add, not JLC SMD. |

## Design decisions to confirm
1. **LDO thermal → SOT-223, PoE-shed via SHTDWN.** 24→3.3V @ ~0.4W is too hot for SOT-23-5 in a sealed box; SOT-223 (with copper) is fine. TPS7B69 only has EN in the SOT-23-5 body, so instead of gating U20's EN for PoE load-shed, the STM drives the **TPS23861 SHTDWN pins** (they're currently strapped high). Cleaner, cooler, one LDO P/N for U18+U20.
2. **Cap voltage derating:** VIN_24V caps ≥ 50V, VBUS_48V caps ≥ 100V. Set these when picking the bulk caps.
3. **Drop RT1 (NTC)** and **DNP RV1 (MOV)** unless you specifically want them.
4. **THT/mechanical parts** (Phoenix terminals, fuse, thermostat) — confirm JLC assembles them or plan to fit them yourself.

## Workflow
Netlist part-defs (pin numbering) get finalized **once footprints are downloaded**,
because the Part() pin numbers must match each footprint's actual pads. Download
order of priority: microSD (Molex 5033981892), vertical USB-C, relay (HFD4/24-S),
LDO SOT-223-4, P-FET SOT-223 (standard, may already be in KiCad).

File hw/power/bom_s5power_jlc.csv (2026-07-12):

Comment | Designator | Footprint | LCSC Part #
10uF/63V | C15,C16,C17 | C_1210_3225Metric | C6120029
4.7uF/100V | C10,C11,C12,C13,C14 | C_1210_3225Metric | C337978
AMS1117-3.3 | U3 | SOT-223-3_TabPin2 | C6186
BSC057N08NS3G | Q2,Q3 | PowerPAK_SO-8_Single | C534354
BZX84C12 | D2 | SOT-23 | C112551
LM5122MHX | U1 | HTSSOP-20-1EP_4.4x6.5mm_P0.65mm_EP3.4x6.5mm_ThermalVias | C77241
PMEG10010ELR-QX | D4 | Nexperia_CFP3_SOD-123W | C5361358
SMBJ33A | D1 | D_SMB | C78419
SQJ409EP | Q1 | PowerPAK_SO-8L_Single | C727776
SS56 | D3 | D_SMC | C2848695
TPS54560DDAR | U2 | SOIC-8-1EP_3.9x4.9mm_P1.27mm_EP2.29x3mm | C31966
XAL1010-222MED | FB1 | L_Coilcraft_XAL1010-XXX | C5125746
XAL1510-333 | L2 | L_Coilcraft_XAL1510-333 | C3911775
100R | R9,R10 | R_0402_1005Metric
100k | R1,R2,R13,R15 | R_0402_1005Metric
100nF | C6,C9,C18 | C_0402_1005Metric
100pF | C8 | C_0402_1005Metric
100uF | C3 | C_1206_3216Metric
10k | R6,R7,R18 | R_0402_1005Metric
10nF | C7 | C_0402_1005Metric
10uF | C1,C2 | C_1210_3225Metric
10uF | C24 | C_0805_2012Metric
13k | R14 | R_0402_1005Metric
15nF | C19 | C_0402_1005Metric
1uF | C4 | C_0603_1608Metric
2.2R | R11,R12 | R_0402_1005Metric
2.2uF | C20,C21 | C_1206_3216Metric
22uF | C22,C23 | C_0805_2012Metric
24.9k | R16 | R_0402_1005Metric
4.7uF | C5 | C_0805_2012Metric
40.2k | R8 | R_0402_1005Metric
440k | R5 | R_0402_1005Metric
45.3k | R4 | R_0402_1005Metric
52.3k | R17 | R_0402_1005Metric
5mohm 2W sense | RS | R_2512_6332Metric
6.8k | R3 | R_0402_1005Metric
Fuse 12A 0452012 | F1 | Fuse_Littelfuse-NANO2-451_453
MOV S14K30 | RV1 | RV_Disc_D9mm_W3.9mm_P5mm
MPS-06-01-RA | J2 | SAMTEC_MPS-06-01-X-X-RA-SD
MSTB2.5/3-GF | J1 | PhoenixContact_MSTB_2,5_3-GF-5,08_1x03_P5.08mm_Horizontal_ThreadedFlange
MountingHole M2.5 | MH1,MH2,MH3,MH4 | MountingHole_2.7mm_M2.5_6mmPad
SRP1245A-220M | L1 | L_Bourns_SRP1245A

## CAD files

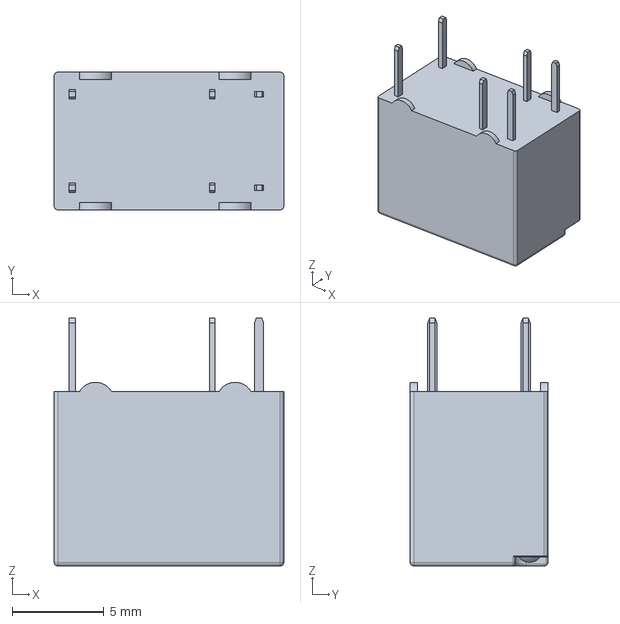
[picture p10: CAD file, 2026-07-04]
hw/core/hongfa-HFD23.step
12.5 x 7.50 x 13.5 mm

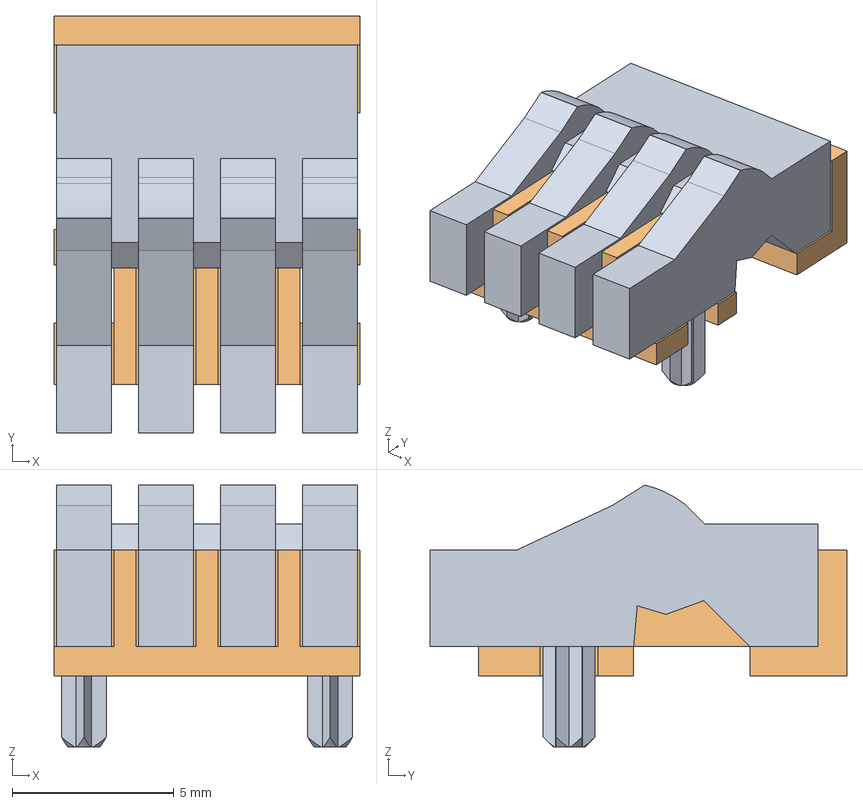
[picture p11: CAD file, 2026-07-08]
hw/core/vendor-3d/Mentor_1278.1004.step
9.47 x 12.9 x 8.10 mm

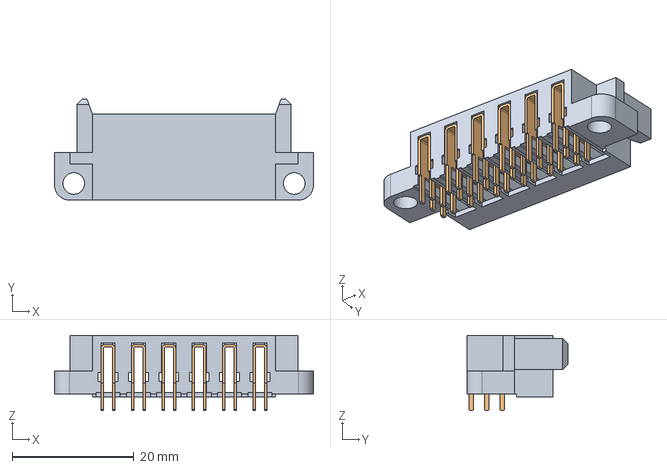
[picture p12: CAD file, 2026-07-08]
hw/power/vendor-3d/MPS-06-01-RA.step
42.6 x 16.7 x 12.4 mm

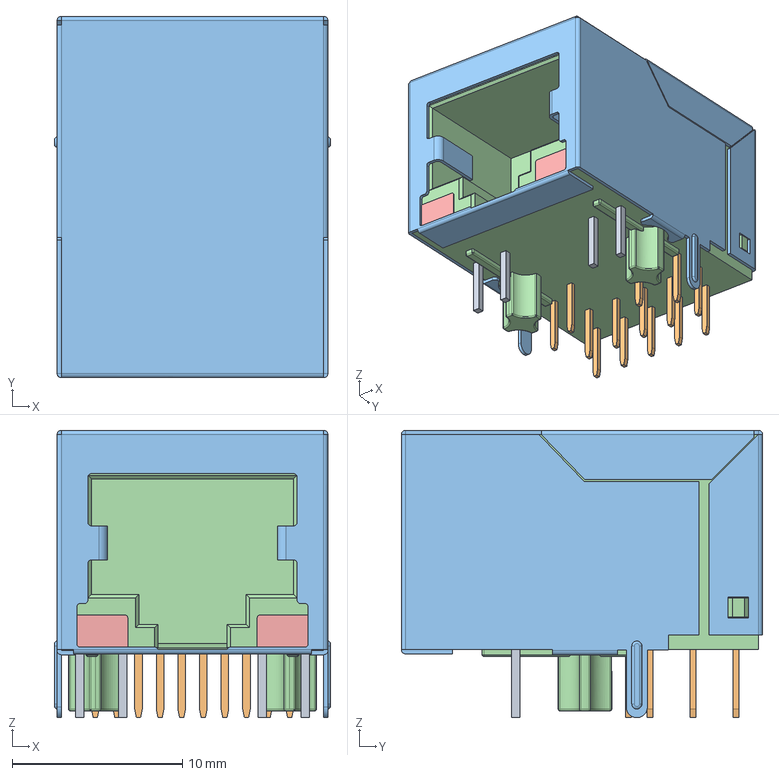
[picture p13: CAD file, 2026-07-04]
hw/core/LPJG0926HENL.step
16.2 x 21.2 x 16.9 mm

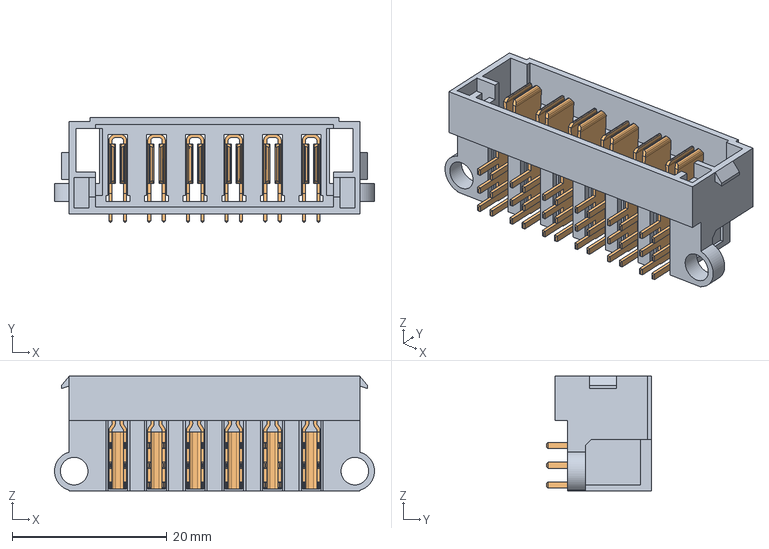
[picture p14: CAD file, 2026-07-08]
hw/core/vendor-3d/MPT-06-01-RA.step
41.4 x 13.5 x 14.8 mm

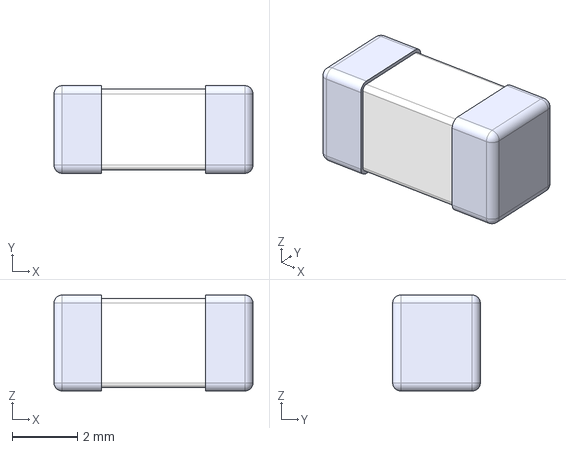
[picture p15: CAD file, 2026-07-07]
hw/power/vendor-3d/Fuse_Littelfuse_0452012.step
6.10 x 2.69 x 2.94 mm

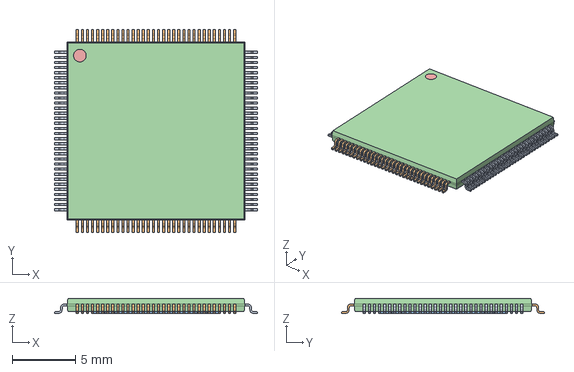
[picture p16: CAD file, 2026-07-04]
hw/core/KSZ9477STXI.step
16.0 x 16.0 x 1.20 mm

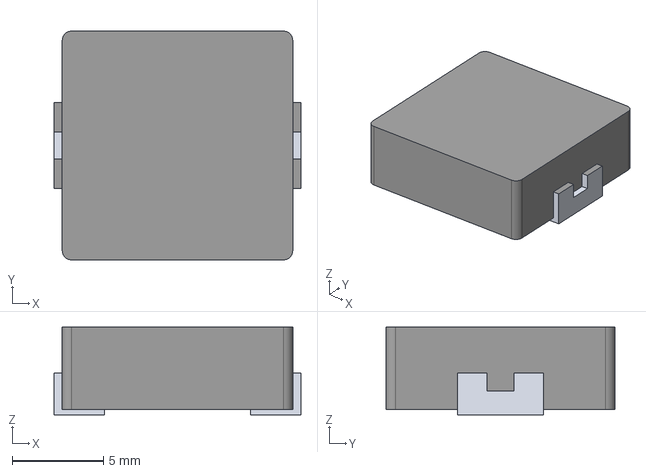
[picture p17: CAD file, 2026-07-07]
hw/power/vendor-3d/L_Bourns_SRP1245A.step
13.5 x 12.5 x 4.80 mm

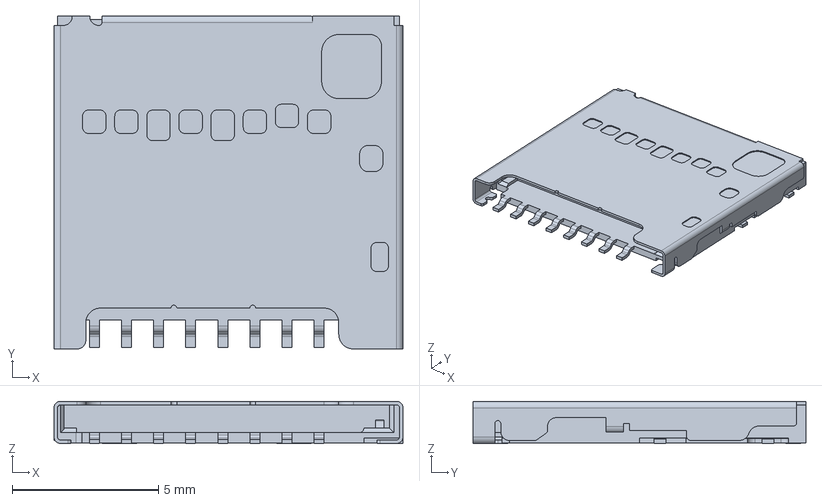
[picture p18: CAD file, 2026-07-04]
hw/core/molex-104031-0811.step
11.9 x 11.4 x 1.45 mm

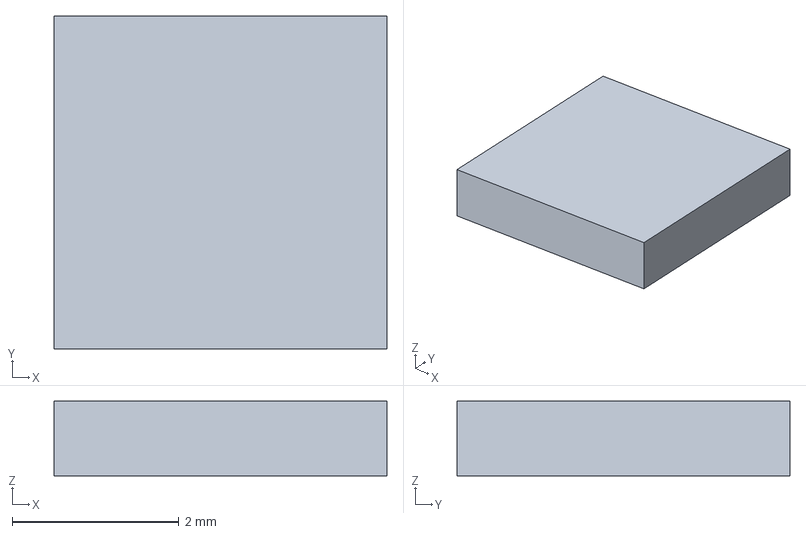
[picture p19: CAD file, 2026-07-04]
hw/core/vendor-3d/QFN-20-1EP_4x4mm_P0.5mm_EP2.7x2.7mm.step
4.00 x 4.00 x 0.9 mm

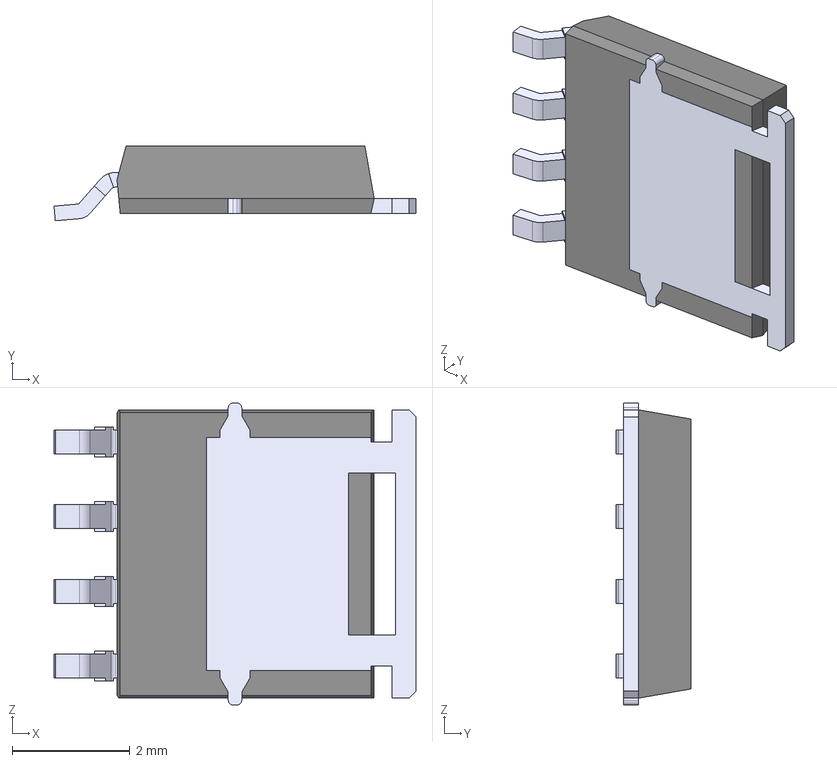
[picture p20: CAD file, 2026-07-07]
hw/power/vendor-3d/PowerPAK_SO-8L.step
6.15 x 1.27 x 5.13 mm

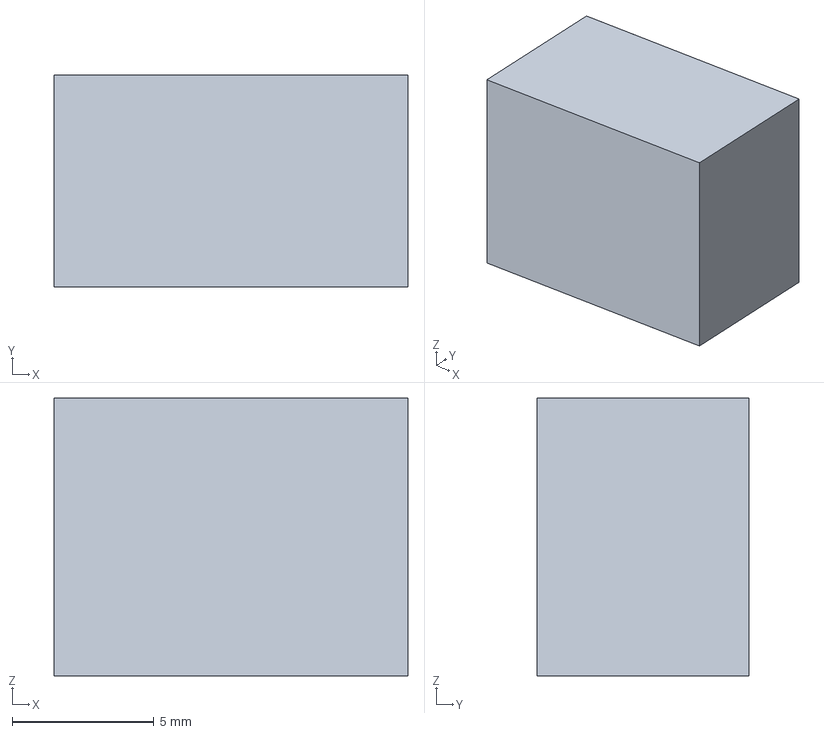
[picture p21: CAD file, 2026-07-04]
hw/core/HFD23_box.step
12.5 x 7.50 x 9.80 mm

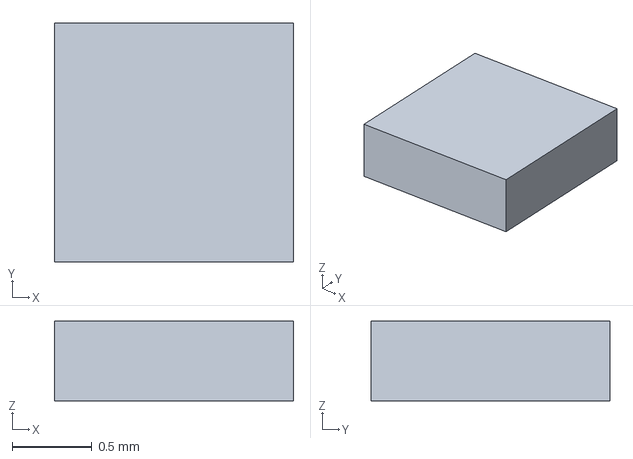
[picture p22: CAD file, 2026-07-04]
hw/core/vendor-3d/Sensirion_DFN-4_1.5x1.5mm_P0.8mm_SHT4x_NoCentralPad.step
1.50 x 1.50 x 0.5 mm

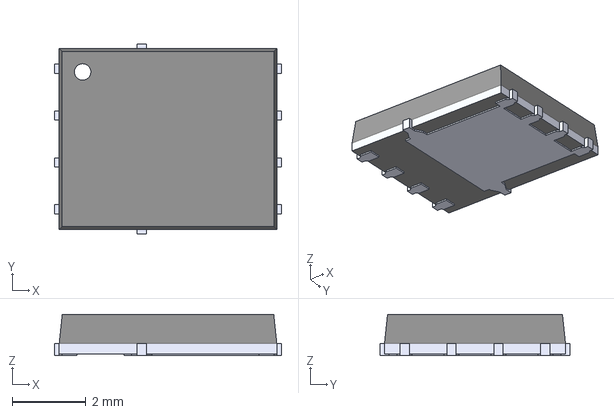
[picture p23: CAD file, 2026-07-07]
hw/power/vendor-3d/PowerPAK_SO-8.step
6.15 x 5.16 x 1.12 mm

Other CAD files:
hw/core/vendor-3d/Crystal_SMD_2016-4Pin_2.0x1.6mm.step
hw/power/vendor-3d/Molex_MicroFit_43045-1200_2x06_RA.step
hw/core/ck-KMR2.step
hw/core/2171820001.step
hw/core/HR911130A.step
hw/core/vendor-3d/SW_Push_1P1T_NO_CK_KMR2.step

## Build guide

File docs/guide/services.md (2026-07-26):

# Services: routing, DHCP, DNS, discovery, time

Everything on this page turns the s5 from a switch into the thing at the centre of a small network. It is all optional and all off until you ask for it — a switch that started handing out addresses on delivery would be a menace on somebody else's network.

## The shape of it

A VLAN with an **address** becomes routable. Give it one and the switch grows an interface in that VLAN (`br0.<vid>`), which is what lets it be a gateway, serve DHCP, answer DNS and reflect discovery there. Without an address a VLAN is still a perfectly good switched VLAN; it just has no presence of its own.

That ordering is worth internalising, because most refusals on this page are it in disguise: DHCP needs an address, mDNS reflection needs an address, inter-VLAN routing needs an address at both ends.

## VLAN identity and switch addresses

    configure
    set vlans.10.name office
    set vlans.10.address 10.10.0.1/24
    set vlans.20.name guest
    set vlans.20.address 10.20.0.1/24
    commit

`show vlans` now reads as one row per VLAN — what it is called, what the switch's address in it is, and which ports are in it:

    vid   name     address        members
     10   office   10.10.0.1/24   lan1(u,pvid) lan4(t)
     20   guest    10.20.0.1/24   lan2(u,pvid) lan4(t)

The **name** is pure configuration — there is nothing on the box to read it back from, so it lives in the commit and survives reboots the same way every other setting does. Deleting a VLAN's address removes its interface; the VLAN itself stays.

## Routing

`routing.enabled` is the master switch for forwarding between VLANs and out of the uplink. Routes with forwarding off are a configuration that looks right and moves no packets, so `show route` puts the forwarding state at the top of the table rather than hiding it in another command.

    set routing.enabled true
    set interfaces.wan.gateway 203.0.113.1
    set routing.static.branch.prefix 192.168.44.0/24
    set routing.static.branch.via 10.20.0.9

There are two ways to name a default route — an interface's `gateway`, or a static route to `0.0.0.0/0` — and setting both is refused rather than resolved arbitrarily.

**The switch owns only the routes it installed.** `show route` marks those `config`; a route the kernel derived from an address, one a DHCP lease brought in, or one your network configuration put there is left alone, and deleting a static route from the configuration removes it from the box on the next commit.

## DHCP

A pool belongs to a VLAN, and the switch has to be in the subnet it is serving:

    set vlans.10.dhcp.enabled true
    set vlans.10.dhcp.range_start 10.10.0.100
    set vlans.10.dhcp.range_end 10.10.0.200
    set vlans.10.dhcp.lease_time 720
    set vlans.10.dhcp.static.aa:bb:cc:dd:ee:ff.ip 10.10.0.50

`lease_time` is in minutes. `gateway` and `dns` default to the switch itself and are there for the cases where they should not be. `vlans.<vid>.dhcp.static.<mac>.ip` is a reservation: that MAC always gets that address.

Pools are per VLAN and stay that way — a client in VLAN 20 is served out of VLAN 20's pool or not at all. A range outside the VLAN's own subnet is refused at commit, because the alternative is a DHCP server that fails to start after the rest of the box has already been reconfigured.

`show dhcp server` lists the pools and how much of each is in use; `show dhcp leases` shows who holds what and for how much longer; `clear dhcp lease <ip|mac>` hands one address back. That last one briefly restarts the server, because the lease database is only read at startup — a quiet edit that left the server holding the old lease would report success and change nothing.

## DNS

The same daemon forwards DNS when you ask it to:

    set dns.serve true
    set dns.local_domain office.lan
    set dns.primary 9.9.9.9
    set dns.secondary 1.1.1.1

`dns.primary` / `dns.secondary` are the switch's own resolvers *and* the upstreams it forwards to. `dns.local_domain` is the domain the switch answers for itself; names it does not know go upstream.

## mDNS reflection

Discovery protocols deliberately do not cross subnets, which is correct and also why the printer in the printer VLAN is invisible from the laptop VLAN. Reflection repeats mDNS between the VLANs you name:

    set mdns.enabled true
    set mdns.reflect.10 true
    set mdns.reflect.20 true

At least two VLANs, each with an address, up to five. Reflecting into one VLAN is refused: it would start a repeater that repeats nothing while reporting itself healthy.

## Time

`ntp.server` points the switch at an upstream. `ntp.serve` additionally makes it answer clients:

    set ntp.server pool.ntp.org
    set ntp.serve true

Serving without a source is refused — a switch handing out time it never synchronised is worse than one handing out none. `show ntp` reports the source, whether we are synchronised, and whether we are serving.

## When a service is not running

Every service on this page is a real daemon, and the switch is honest about them in both directions.

**At commit time**: a feature whose daemon is not installed on the box **fails the commit**. Configuring DHCP on an image without dnsmasq gives you an error, not a clean commit and a phone that never gets an address.

**At any other time**: `show system services` is where you find out that something died after it started.

    show system services
    service         state             role
    mstpd           running           rstp loop protection on br0
    lldp            running           advertising on 5 port(s) every 30s
    dnsmasq         DOWN              2 DHCP pool(s), DNS on
    mdns-repeater   not configured    mDNS reflection between VLANs

`DOWN` means the configuration asks for it and it is not there — the row this command exists for. Re-committing restarts it; init restarts it after a crash.

## Generated configuration is not yours to edit

dnsmasq's configuration file, the LLDP daemon's, and the mDNS repeater's arguments are all **apply artifacts**. They are rewritten from the committed configuration on every commit and every boot, they say so in their first line, and anything you edit into them is gone at the next commit. The CLI is the whole configuration surface; there is deliberately no supported way in underneath it.

That is also why hostile values fail rather than being escaped: these formats have no quoting, so a newline inside a domain name or an address would be a new directive. There is no safe escaping of that — only refusal, at commit, naming the path you set.

## Not locking yourself out

Changing the address, VLAN, route or port your own session is riding on is a legitimate thing to do and a well-known way to lose a switch. The s5 will not stop you, but it will tell you before it happens — on `show diff` as well as on `commit`:

    warning: this session reaches the switch on VLAN 10 (10.10.0.1), and
    this commit changes vlans.10.address — consider `commit confirmed 5`

`commit confirmed <minutes>` applies the change and arms an automatic revert: if you do not type `confirm` within the window, the box rolls itself back. The timer lives in the switch, not in your session, so losing the connection is exactly the case it handles — and if the power goes out during the window, the boot reverts it too. See [configuration.md](configuration.md) for the full lifecycle.

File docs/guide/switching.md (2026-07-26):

# Switching features

## The fabric

The switch fabric is built by the box itself at boot: bridge `br0` with VLAN filtering over ports **lan1–lan4**; **lan5 is routed** (kept out of the bridge for the WAN/uplink role). `show fabric` reports the live fabric state — bridge present, members enslaved, anything detached or absent.

## VLANs

Port membership lives under `ports.<port>.vlan.<vid>` with four modes: `untagged-pvid` (access port — untagged in and out, this VID is the port's default), `tagged` (trunk member), `untagged`, and `pvid`. A port configured with any VLANs owns its full set — VIDs on the box but absent from config are removed at commit.

Access + trunk in one commit:

    configure
    set ports.lan1.vlan.10 untagged-pvid
    set ports.lan2.vlan.10 untagged-pvid
    set ports.lan3.vlan.20 untagged-pvid
    set ports.lan4.vlan.10 tagged
    set ports.lan4.vlan.20 tagged
    delete ports.lan1.vlan.1
    show diff
    commit

`show vlans` renders the resulting table.

## Ports

`ports.<port>.enabled` is the administrative state (survives reboots — a shut port stays shut through a power cut). `ports.<port>.{speed,duplex,autoneg}` force link parameters (default auto), `mtu` sets frame size (the CPU-path conduit MTU is maintained automatically), `flow_control` toggles pause frames. `show interfaces` for the summary, `show interfaces detail <port>` for negotiated-vs-configured link state and full counters, `clear counters [port]` to baseline them (counters are operational state: a reboot genuinely resets them).

## Loop protection (spanning tree)

**Rapid spanning tree is on in the factory configuration**, and it is the one feature you should think twice before turning off. A switch with a loop in it does not degrade — it saturates, and it takes the management path with it, so the operator who could fix it is the one who cannot reach it any more.

`stp.mode` is `rstp` (802.1w, the default), `stp` (classic 802.1D, for peers that cannot speak rapid) or `off`. `stp.priority` decides the root election: **lowest wins**, and the value is one of the sixteen legal multiples of 4096 that TAB will offer you. Make the switch at the centre of your topology the root deliberately rather than letting MAC addresses decide it:

    configure
    set stp.mode rstp
    set stp.priority 4096
    commit

`show spanning-tree` answers the two questions you actually have: who is root, and what is each port doing. A port in `discarding` is not broken — it is the spanning tree doing its job, holding one side of a loop open.

Per port, `ports.<port>.stp.cost` (0 derives it from link speed) and `ports.<port>.stp.priority` steer path selection. Two more matter operationally:

- **`edge`** — an access port with a desk on it. An edge port forwards immediately instead of waiting out the listening and learning delays, which is the difference between a phone that boots and one that gives up on DHCP. Set it on ports that face endpoints, never on ports that face switches.
- **`bpdu_guard`** — the other half of the same statement. If a port you declared to be an endpoint port starts receiving spanning-tree messages, somebody has patched a switch into it, and the topology you designed is no longer the one running. The guard takes that port out of service and raises an alarm:

        show system            # alarms: bpdu-guard blocked lan2 — ...
        show spanning-tree     # lan2 ... BLOCKED

  The port stays down until you say otherwise, which is the point — `clear spanning-tree bpdu-guard lan2` returns it to service and is your assertion that the loop is gone.

The three bridge timers (`hello`, `max_age`, `forward_delay`) are tied together by the standard: `2 × (forward_delay − 1) ≥ max_age ≥ 2 × (hello + 1)`. A combination that breaks the relationship is refused at commit, with the constraint you broke in the message, rather than being half-applied. Leave them alone unless you have a reason.

`show spanning-tree statistics` counts BPDUs and state transitions per port — a port whose transition count keeps climbing has a flapping link behind it. `clear spanning-tree statistics` re-baselines them.

Spanning tree only applies to bridged ports; configuring it on the routed uplink is refused. On hardware without mstpd installed, a spanning-tree commit **fails** rather than quietly leaving the network unguarded.

## Neighbours (LLDP)

LLDP is on by default. The switch announces itself on every port and records what it hears, so `show neighbors` answers "what is actually on the other end of this cable" without a site visit:

    show neighbors
    port   chassis             system       their port   mgmt address
    lan2   aa:bb:cc:00:00:07   core-sw      ge-0/0/1     10.0.0.1

`lldp.tx_interval` sets how often we announce (default 30 seconds; a neighbour drops us after four missed announcements). `lldp.port.<port>.enabled` turns it off per port — worth doing on a port facing an untrusted network, since LLDP tells whoever is listening your hostname and management address.

Neighbours age out on the TTL they advertised: a table that still listed a switch you unplugged would be worse than an empty one.

## MAC table

`show mac-table [port]` labels each entry: `dynamic` (learned, ages out after `mac.aging_time` seconds), `static` (configured via `mac.static.<mac>.{port,vlan}`), and the kernel's own `local`/`multicast` entries, which are not configuration and cannot be deleted. `clear mac-table [port]` flushes **learned entries only** — an operational verb never deletes configuration.

## Multicast

IGMP snooping is on by default (`igmp_snooping.enabled`): multicast is pruned to ports that joined the group. On an L2 with no multicast router, enable `igmp_snooping.querier` so membership reports keep flowing. `show igmp-snooping groups` lists current groups.

## PoE

`poe.<port>.enabled` and `poe.<port>.power_limit_mw` control power delivery per port (ports 1–5); `show poe` reports per-port state, class, and drawn power; `poe reset <port>` power-cycles a device. Budget/priority management is planned (WP1.9) but not yet implemented. On hardware without the PoE controller, `poe.*` configuration is rejected at commit rather than silently accepted.

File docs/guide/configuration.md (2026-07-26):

# The configuration model

The s5 is configured like a Junos-class switch: you edit a **candidate**, inspect the difference, and **commit** — the box then applies the whole result to hardware transactionally. Nothing you type takes effect before `commit`, and a failed commit applies nothing.

## Editing

`configure` opens the candidate session and the prompt changes from `>` to `#`. Only one session can hold configure mode: a second operator is refused by name (`configure mode is held by karl (session confd-…)`) and an admin can take it over with `configure force`, which discards the holder's candidate. The lock dies with its session — a crashed or disconnected CLI never leaves configure mode stuck.

Inside the session: `set <path> <value>` and `delete <path>` edit the candidate; TAB completes paths segment by segment and values from the schema; `show diff` shows exactly what commit would do (`+` added, `~` changed with the previous value, `-` removed); `exit` leaves configure mode and discards the candidate (as does `rollback candidate`).

Values are validated twice: at `set` against the schema (types, ranges, enum members) and at commit against the hardware — a candidate the box rejects is applied not at all, never halfway.

## Committing

- `commit` — apply the candidate, record it as a numbered revision, close the session.
- `commit confirmed <minutes>` — apply AND arm an auto-revert: if you do not type `confirm` within the window, the box rolls itself back. This is the anti-lockout tool — use it for any change that could cut off your own access (management address, VLAN of the port you came in on). The timer lives in the box, not your SSH session: disconnecting cannot stop the revert, and if power is cut during the window, the **boot reverts it** (an unconfirmed change never becomes permanent by accident).
- A second `commit` inside the window confirms implicitly — the new commit is now what runs.

## History and rollback

Every commit is durable and listed by `show commits`; `show commit <id>` shows its diff against the previous revision. `rollback previous` re-applies the next-to-last revision (as a NEW commit — history only moves forward); `rollback to <id>` re-applies any revision. Both prompt for confirmation.

## Named configurations and rescue

`save <name>` stores the running configuration as a named file; `show configs` lists them; `load <name> merge|replace` pulls one into a candidate (merge overlays, replace substitutes) — commit applies it. `load factory` stages the shipped factory defaults. `rescue` is a reserved name: `save rescue` marks the current configuration as the known-good fallback and `rollback rescue` returns to it; the rescue file survives factory reset by design.

## Boot behaviour

The box **boots into its committed configuration**: an init oneshot rebuilds the switch fabric and re-applies the last committed revision before login is possible. `show system boot` reports what that boot did — applied revision, per-step timing (fabric, config apply), and crucially whether the restore ran **this** boot at all (it is keyed to the kernel boot id, so a boot where the restore was skipped cannot hide behind an old healthy report). If the box's live state disagreed with committed intent at boot (out-of-band edits), `show system` raises a `config-divergence` row and the audit log records it.

## Audit

Every mutating command — CLI or (future) web UI, they share one engine — lands in the audit log with user, role, command, and outcome, including automatic events (auto-revert, boot restore, divergence).

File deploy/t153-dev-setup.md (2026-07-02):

# Luckfox Lume (T153) dev-board setup

The T153 Lume is a **software dev target only** — it runs the stock
Luckfox Buildroot image. Production images target the T113-S3 with a
clean mainline Buildroot (see `deploy/README.md`).

Everything einheit-specific lives under **`/mnt/UDISK/einheit/`** (the
writable data partition), so the rootfs stays essentially stock and a
reflash wipes nothing of ours that we can't restore from this repo.

## What we changed on the stock rootfs (minimal, documented)

| Location | Change | Reset |
|---|---|---|
| `/etc/passwd` | added `admin` (uid 1000), `oper` (uid 1001), shell `/bin/bash` | `deluser admin; deluser oper` |
| `/root/.ssh/authorized_keys` | added khruskowski admin key | remove the line |
| `/usr/bin/cli` | symlink -> `/mnt/UDISK/einheit/bin/einheit_s5` | `rm /usr/bin/cli` |
| `/etc/profile.d/einheit.sh` | `cli` alias + admin/oper auto-launch | `rm /etc/profile.d/einheit.sh` |
| `/mnt/UDISK/einheit/` | all einheit binaries + configs | `rm -rf /mnt/UDISK/einheit` |
| `/home` perms | `chmod 755 /home` | (leave — this is the correct default) |

**GOTCHA (fixed):** stock Luckfox image ships `/home` as `drwx------`
(700, root:root). sshd drops to the target uid to read
`~/.ssh/authorized_keys`, but a non-root user can't traverse into a
700 `/home`, so pubkey auth silently fails ("Could not open authorized
keys: Permission denied" only visible with `sshd -ddd`). Root works
because `/root` is a separate path. Fix: `chmod 755 /home`. The
production Buildroot image must ship `/home` as 755.

**GOTCHA (fixed) — root umask 077:** the T153 root shell has
`umask 077`, so everything created as root came out root-only and
locked out admin/oper. Symptoms: `cli: command not found` and the
CLI auto-launch not firing on admin login. All of these need world
read/exec:
- `/mnt/UDISK/einheit` + `/mnt/UDISK/einheit/bin` -> `chmod 755`
  (traversable)
- `/mnt/UDISK/einheit/bin/einheit_s5` -> `chmod 755` (execable)
- `/etc/profile.d/einheit.sh` -> `chmod 644` (readable — else
  /etc/profile's `for i in /etc/profile.d/*.sh` skips it and neither
  the `cli` alias nor the admin/oper auto-launch loads)

The production Buildroot image must install these with correct perms
(755 dirs/binaries, 644 profile scripts) rather than inheriting a
077 umask.

**GOTCHA — admin `ping` needs unprivileged ICMP:** busybox `ping`
uses raw sockets (needs root/CAP_NET_RAW), so `ping` from the CLI as
admin fails ("permission denied, are you root?"). This image has no
`setcap` and ping is a busybox symlink, so there's no clean dev-board
fix (setuid-ing busybox would give every applet root — don't).
Production image fix: ship **iputils** `ping` (`BR2_PACKAGE_IPUTILS`),
which uses SOCK_DGRAM ICMP and honours
`net.ipv4.ping_group_range` (set to `0 2147483647` in
`/etc/sysctl.d/99-einheit-ping.conf`). Then admin ping works with no
setuid/caps.

Root shell was left as `/bin/bash` (stock). We temporarily set it to
the CLI earlier and reverted it — that was the SCP-breaking mistake.

## Deploy / update the binary

```sh
scp build-arm/einheit_s5 \
    root@<ip>:/mnt/UDISK/einheit/bin/einheit_s5
```

The `/usr/bin/cli` symlink already points there, so no other step.

## Login + privilege model

`cli` is a **setuid-root launcher** (`einheit-launch`, installed
`root:root` mode `4755`) — the single privilege boundary. It resolves
the real caller by uid, whitelists accounts, sets `EINHEIT_USER`/
`EINHEIT_ROLE`, scrubs the environment, and execs the CLI:

| Caller | Privilege after launcher | Role |
|---|---|---|
| `root`  | root | admin |
| `admin` | **becomes root** (`setuid(0)`) | admin — all commands, incl. `shell` |
| `oper`  | **drops to uid 1001** (unprivileged) | operator — read-only; `set`/`shell` gated |
| other | rejected ("not authorized") | — |

So `set hostname`, `reboot`, etc. execute as root for admin, while
operator gets a read-only CLI running unprivileged (defence in depth:
even a role-gating bug can't touch the system because the process
isn't root). `admin`/`oper` login `exec`s the launcher, so exiting
the CLI logs out (Juniper-style); admin reaches a root shell via the
in-CLI `shell` command. `root` login -> bash (dev/UART maintenance).

Install (already done on the T153; production image must replicate):
```sh
install -o root -g root -m 4755 einheit-launch \
    /mnt/UDISK/einheit/bin/einheit-launch
ln -sf /mnt/UDISK/einheit/bin/einheit-launch /usr/bin/cli
```

## Full reset to stock

```sh
deluser admin 2>/dev/null; deluser oper 2>/dev/null
rm -f /usr/bin/cli /etc/profile.d/einheit.sh
rm -rf /mnt/UDISK/einheit
# optionally trim /root/.ssh/authorized_keys
```

Or reflash the stock image from the Luckfox SDK — nothing of ours is
in the rootfs image itself, only the runtime changes above.

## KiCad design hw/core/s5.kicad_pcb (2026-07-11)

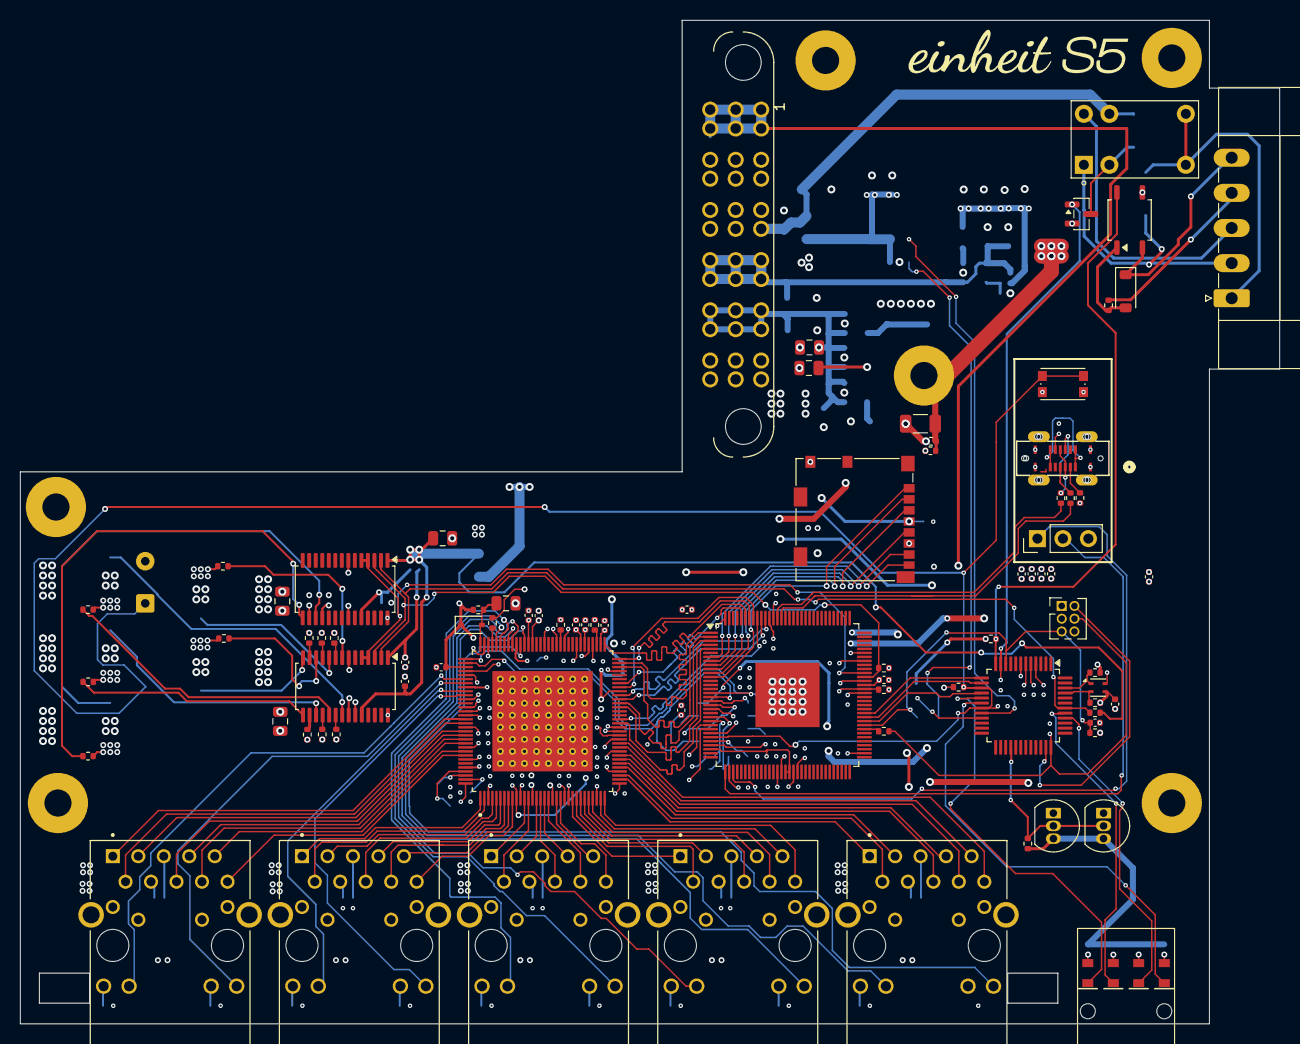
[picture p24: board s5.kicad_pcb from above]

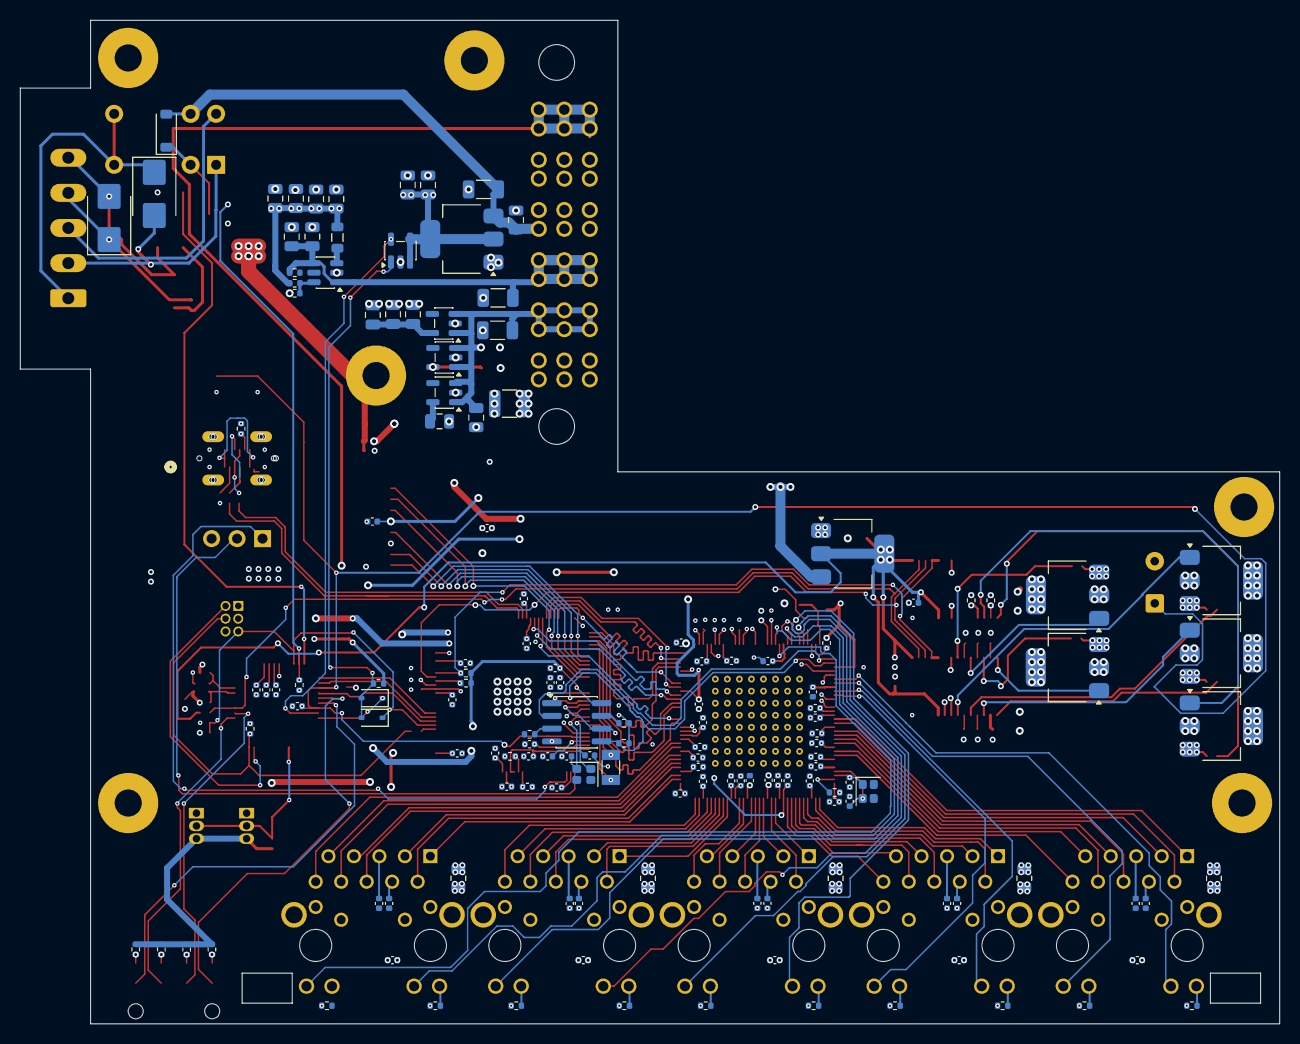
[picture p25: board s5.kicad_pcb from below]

Board: 4 copper layers, 125.5 x 100.0 mm, 236 parts (143 on the bottom side), 197 nets.

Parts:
C1: 10uF; C_1210_3225Metric
C2, C3, C4: 10uF; C_1206_3216Metric
C5, C8, C9, C10, C11, C12, C13, C14, C15, C16, C51, C90, C91, C98, C100: 10uF; C_0805_2012Metric
C6, C7: 22uF; C_0805_2012Metric
C17, C18, C19, C20, C21, C22, C23, C24, C25, C26, C27, C28, C29, C30, C31, C32, C33, C34, C35, C36, C37, C38, C39, C40, C41, C42, C43, C44, C45, C46, C47, C48, C52, C53, C54, C55, C56, C57, C58, C59, C60, C61, C62, C64, C68, C69, C70, C71, C72, C73, C74, C75, C76, C77, C78, C79, C80, C81, C82, C83, C84, C85, C86, C87, C88, C89, C94, C95, C96, C97, C99, C101, C102, C103, C104, C106, C107, C108, C109: 100nF; C_0402_1005Metric
C49, C50: 15pF; C_0402_1005Metric
C63, C65: 100nF; C_0805_2012Metric
C66, C67: 1uF; C_0402_1005Metric
C92, C93: 18pF; C_0402_1005Metric
C105: 4.7uF; C_0805_2012Metric
C110: 4.7nF; C_1206_3216Metric
D2: 1N4148; D_SOD-323
D3: LG M676 green; Osram_MiniTOPLED_LSM676
D4: LY M676 yellow; Osram_MiniTOPLED_LSM676
D5: LO M676 orange; Osram_MiniTOPLED_LSM676
D6: LS M676 red; Osram_MiniTOPLED_LSM676
D52, D53: BAT54; D_SOD-323
D54, D56: 1N4148W; D_SOD-123
D55, D57: SMBJ33CA; D_SMB
J2, J3, J4, J5, J6: LPJG0926HENL
J7: Conn_01x03; PinHeader_1x03_P2.54mm_Vertical
J8: microSD; microSD_HC_Molex_104031-0811
J9: MPT-06-01-RA; MPT-06-01-XX-X-RA-SD
J10: SWD_2x3; PinHeader_2x03_P1.27mm_Vertical
J11: MC1,5/5-GF-3,5_1843826; PhoenixContact_MC_1,5_5-GF-3.5_1x05_P3.50mm_Horizontal_Thre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
J12: USB-C_2171820001; CONN_2171820001_MOL
K1: HFD23-024-1ZS; Relay_HFD23_1C_THT
L1: 1uH; L_0805_2012Metric
LP1: Mentor 1278.1004 4-way bargraph light guide; Mentor_1278.1004_LightGuide
MH1, MH2, MH3, MH4, MH5, MH6: MountingHole_M2.5_PE; MountingHole_2.7mm_M2.5_6mmPad
Q1, Q2, Q3, Q4, Q5: NMOS; SOT-223-3_TabPin2
Q60: 2N7002; SOT-23
R1, R3, R63: 100k; R_0402_1005Metric
R2: 50k; R_0402_1005Metric
R4: 6.04k; R_0402_1005Metric
R5: 191; R_0402_1005Metric
R6, R9, R10, R11, R44, R45, R46, R47, R55, R56, R57, R65: 10k; R_0402_1005Metric
R7, R8, R41, R42, R59, R60, R61, R64: 4.7k; R_0402_1005Metric
R12, R58: 1k; R_0402_1005Metric
R13, R14, R15, R16, R17, R18, R19, R20, R21, R22: 150; R_0402_1005Metric
R23, R26, R29, R32, R37: 47; R_0402_1005Metric
R24, R27, R30, R33, R38: 0.25; R_0805_2012Metric
R25, R28, R31, R34, R35, R36, R39, R40: 22; R_0402_1005Metric
R43: 240; R_0402_1005Metric
R48, R49: 27; R_0402_1005Metric
R50, R51: 5.1k; R_0402_1005Metric
R52, R53, R54, R62: 270; R_0402_1005Metric
R66: 1M; R_0402_1005Metric
R67: 0R; R_0402_1005Metric
SW2: SW_Push; SW_Push_1P1T_NO_CK_KMR2
TS1: Thermostat_NO_95C; SolderWire-0.25sqmm_1x02_P4.2mm_D0.65mm_OD1.7mm
U1: KSZ9477S; QFP40P1600X1600X120-129N
U3: AP2112K-2.5; SOT-23-5
U4: AP2112K-1.2; SOT-23-5
U7: T113-S3; eLQFP-128-1EP_14x14mm_P0.4mm
U8: W25N02JWZEIF; SOIC-8_3.9x4.9mm_P1.27mm
U9, U13: TPS23861; TSSOP-28_4.4x9.7mm_P0.65mm
U10: TPS3823; SOT-23-5
U11: TLV62569PDDCR; SOT-23-6
U12: AP2112K-1.8; SOT-23-5
U15, U16: DS18B20; TO-92_Inline
U17: SHT40-AD1B; Sensirion_DFN-4_1.5x1.5mm_P0.8mm_SHT4x_NoCentralPad
U18, U20: TPS7B6933QDCYRQ1; SOT-223-3_TabPin2
U19: STM32G071CBTx; LQFP-48_7x7mm_P0.5mm
U21: EL357N; SOP-4_3.8x4.1mm_P2.54mm
Y1: 25MHz; Crystal_SMD_2016-4Pin_2.0x1.6mm
Y2: 24MHz; Crystal_SMD_2016-4Pin_2.0x1.6mm
Y3: 32.768kHz; Crystal_SMD_3215-2Pin_3.2x1.5mm

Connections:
CORE_PG: R1.2, U11.5
CORE_SW: L1.1, U11.3
DI_LED_A: D56.2, R64.2, U21.1
DI_SENSE: R65.2, U19.12, U21.4
DI_TERM_N: D56.1, D57.2, J11.5, U21.2
DI_TERM_P: D57.1, J11.4, R64.1
FB_0V9: R2.2, R3.1, U11.6
FLASH_CS: U7.18, U8.1
FLASH_HOLD: R46.2, U8.7
FLASH_WP: R45.2, U8.3
GND: C1.2, C2.2, C3.2, C4.2, C5.2, C6.2, C7.2, C8.2, C9.2, C10.2, C11.2, C12.2, C13.2, C14.2, C15.2, C16.2, C17.2, C18.2, C19.2, C20.2, C21.2, C22.2, C23.2, C24.2, C25.2, C26.2, C27.2, C28.2, C29.2, C30.2, C31.2, C32.2, C33.2, C34.2, C35.2, C36.2, C37.2, C38.2, C39.2, C40.2, C41.2, C42.2, C43.2, C44.2, C45.2, C46.2, C47.2, C48.2, C49.2, C50.2, C51.2, C52.2, C53.2, C54.2, C55.2, C56.2, C57.2, C58.2, C59.2, C60.2, C61.2, C62.2, C63.2, C64.2, C65.2, C66.2, C67.2, C68.2, C69.2, C70.2, C71.2, C72.2, C73.2, C74.2, C75.2, C76.2, C77.2, C78.2, C79.2, C80.2, C81.2, C82.2, C83.2, C84.2, C85.2, C86.2, C87.2, C88.2, C89.2, C90.2, C91.2, C92.2, C93.2, C94.2, C95.2, C96.2, C97.2, C98.2, C99.2, C100.2, C101.2, C102.2, C103.2, C104.2, C105.2, C106.2, C107.2, C108.2, C109.2, C110.1, J2.13, J2.14, J2.S1, J2.S2, J3.13, J3.14, J3.S1, J3.S2, J4.13, J4.14, J4.S1, J4.S2, J5.13, J5.14, J5.S1, J5.S2, J6.13, J6.14, J6.S1, J6.S2, J7.3, J8.6, J8.10, J9.7, J9.8, J9.9, J9.10, J9.11, J9.12, J10.3, J12.A1, J12.A12, J12.B1, J12.B12, J12.MNT2, J12.S1, J12.S2, J12.S3, J12.S4, Q60.2, R3.2, R4.2, R5.2, R12.2, R35.2, R36.2, R40.2, R43.2, R50.2, R51.2, R57.2, R63.2, R66.1, R67.1, SW2.2, TS1.2, U1.46, U1.47, U1.69, U1.75, U1.77, U1.80, U1.107, U1.109, U1.123, U1.129, U1.E_1, U1.E_2, U1.E_3, U1.E_4, U1.E_5, U1.E_6, U1.E_7, U1.E_8, U1.E_9, U1.E_10, U1.E_11, U1.E_12, U1.E_13, U1.E_14, U1.E_15, U1.E_16, U1.E_17, U1.E_18, U1.E_19, U1.E_20, U1.E_21, U1.E_22, U1.E_23, U1.E_24, U1.E_25, U1.E_26, U1.E_27, U1.E_28, U1.E_29, U1.E_30, U1.E_31, U1.E_32, U1.E_33, U1.E_34, U1.E_35, U1.E_36, U1.E_37, U1.E_38, U1.E_39, U1.E_40, U1.E_41, U1.E_42, U1.E_43, U1.E_44, U1.E_45, U1.E_46, U1.E_47, U1.E_48, U1.E_49, U1.E_50, U1.E_51, U1.E_52, U1.E_53, U1.E_54, U1.E_55, U1.E_56, U1.E_57, U1.E_58, U1.E_59, U1.E_60, U1.E_61, U1.E_62, U1.E_63, U1.E_64, U3.2, U4.2, U7.91, U7.129, U8.4, U9.7, U9.22, U9.23, U10.2, U11.2, U12.2, U13.7, U13.22, U15.1, U16.1, U17.4, U18.1, U19.7, U20.1, U21.3
IBA: R12.1, U1.67
INTRP_N: R9.2, U1.94, U7.82
KSZ_ISET: R4.1, U1.127
KSZ_RESET_N: C51.1, D2.2, R6.2, U1.96
KSZ_S_REXT: R5.1, U1.76
KSZ_XI: C49.1, U1.126, Y1.1
KSZ_XO: C50.1, U1.125, Y1.2
LED_ALM_A: D6.1, R62.2
LED_FAULT: D5.2, U19.41
LED_FAULT_A: D5.1, R54.2
LED_PWR: D3.2, U19.18
LED_PWR_A: D3.1, R52.2
LED_STATUS: D4.2, U19.40
LED_STA_A: D4.1, R53.2
MAIN_EN: D53.1, J9.1, J9.2, J9.3, J9.4, J9.5, J9.6, U19.21
MCU_ALARM: D6.2, U19.17
MCU_BOOT0_CTL: R58.1, U7.72
MCU_NRST: C106.1, D52.1, J10.5, R56.2, U7.73, U19.10
MCU_SWCLK: J10.4, R57.1, R58.2, U19.36
MCU_SWDIO: J10.2, U19.35
P1_AN: J2.2, U1.2
P1_AP: J2.1, U1.1
P1_BN: J2.6, U1.5
P1_BP: J2.3, U1.4
P1_CN: J2.8, U1.7
P1_CP: J2.7, U1.6
P1_CT1: C52.1, J2.4
P1_CT2: C53.1, J2.5
P1_DN: J2.10, U1.9
P1_DP: J2.9, U1.8
P1_GRN: J2.16, U1.105
P1_GRN_A: J2.15, R13.2
P1_YEL: J2.18, U1.106
P1_YEL_A: J2.17, R14.2
P2_AN: J3.2, U1.13
P2_AP: J3.1, U1.12
P2_BN: J3.6, U1.16
P2_BP: J3.3, U1.15
P2_CN: J3.8, U1.18
P2_CP: J3.7, U1.17
P2_CT1: C54.1, J3.4
P2_CT2: C55.1, J3.5
P2_DN: J3.10, U1.21
P2_DP: J3.9, U1.20
P2_GRN: J3.16, U1.91
P2_GRN_A: J3.15, R15.2
P2_YEL: J3.18, U1.92
P2_YEL_A: J3.17, R16.2
P3_AN: J4.2, U1.25
P3_AP: J4.1, U1.24
P3_BN: J4.6, U1.27
P3_BP: J4.3, U1.26
P3_CN: J4.8, U1.29
P3_CP: J4.7, U1.28
P3_CT1: C56.1, J4.4
P3_CT2: C57.1, J4.5
P3_DN: J4.10, U1.32
P3_DP: J4.9, U1.31
P3_GRN: J4.16, U1.88
P3_GRN_A: J4.15, R17.2
P3_YEL: J4.18, U1.89
P3_YEL_A: J4.17, R18.2
P4_AN: J5.2, U1.35
P4_AP: J5.1, U1.34
P4_BN: J5.6, U1.38
P4_BP: J5.3, U1.37
P4_CN: J5.8, U1.40
P4_CP: J5.7, U1.39
P4_CT1: C58.1, J5.4
P4_CT2: C59.1, J5.5
P4_DN: J5.10, U1.43
P4_DP: J5.9, U1.42
P4_GRN: J5.16, U1.85
P4_GRN_A: J5.15, R19.2
P4_YEL: J5.18, U1.86
P4_YEL_A: J5.17, R20.2
P5_AN: J6.2, U1.113
P5_AP: J6.1, U1.112
P5_BN: J6.6, U1.116
P5_BP: J6.3, U1.115
P5_CN: J6.8, U1.118
P5_CP: J6.7, U1.117
P5_CT1: C60.1, J6.4
P5_CT2: C61.1, J6.5
P5_DN: J6.10, U1.121
P5_DP: J6.9, U1.120
P5_GRN: J6.16, U1.102
P5_GRN_A: J6.15, R21.2
P5_YEL: J6.18, U1.103
P5_YEL_A: J6.17, R22.2
PE: C110.2, MH1.1, MH2.1, MH3.1, MH4.1, MH5.1, MH6.1, R66.2, R67.2
PME_N: R10.2, U1.93
POE_VP_1: J2.11, J2.12, R24.2
POE_VP_2: J3.11, J3.12, R27.2
POE_VP_3: J4.11, J4.12, R30.2
POE_VP_4: J5.11, J5.12, R33.2
POE_VP_5: J6.11, J6.12, R38.2
PSE_I2C_SCL: R42.2, U7.85, U9.3, U13.3
PSE_I2C_SDA: R41.2, U7.86, U9.4, U9.5, U13.4, U13.5
PSE_RESET_N: R55.2, U9.2, U13.2, U19.42
RELAY_COM: D55.1, J11.1, K1.3, K1.6
RELAY_DRV: D54.1, K1.2, Q60.3
RELAY_GATE: Q60.1, R63.1, U19.11
RELAY_NC: J11.3, K1.4
RELAY_NO: D55.2, J11.2, K1.1
RGMII_RXD0: U1.65, U7.123
RGMII_RXD1: U1.64, U7.122
RGMII_RXD2: U1.63, U7.1
RGMII_RXD3: U1.62, U7.2
RGMII_RX_CLK: U1.57, U7.121
RGMII_RX_CTL: U1.58, U7.124
RGMII_TXD0: U1.55, U7.118
RGMII_TXD1: U1.54, U7.119
RGMII_TXD2: U1.53, U7.3
RGMII_TXD3: U1.52, U7.4
RGMII_TX_CLK: U1.48, U7.5
RGMII_TX_CTL: U1.49, U7.120
SD_CLK: J8.5, U7.9
SD_CMD: J8.3, U7.10
SD_D0: J8.7, U7.8
SD_D1: J8.8, U7.7
SD_D2: J8.1, U7.12
SD_D3: J8.2, U7.11
SOC_RESET_N: C94.1, R44.2, SW2.1, TS1.1, U7.27, U19.15, U19.19
SPI_CLK: U1.101, U7.19, U8.6
SPI_CS_N: R8.2, U1.100, U7.84
SPI_MISO: U1.97, U7.16, U8.2
SPI_MOSI: R7.2, U1.98, U7.17, U8.5
STM_WDI: U10.5, U19.20
STM_WD_RST: D52.2, D53.2, R47.2, U10.1
SUP_1WIRE: R59.2, U15.2, U16.2, U19.28
SUP_HEARTBEAT: U7.74, U19.16
SUP_I2C_SCL: R60.2, U17.2, U19.45
SUP_I2C_SDA: R61.2, U17.1, U19.46
SUP_MCU_TO_T113: U7.76, U19.13
SUP_T113_TO_MCU: U7.75, U19.14
SYNCLKO: R11.2, U1.95
T113_DXIN: C92.1, U7.23, Y2.1
T113_DXOUT: C93.1, U7.22, Y2.2
T113_DZQ: R43.1, U7.47
T113_LDOA_OUT: C67.1, U7.28
T113_LDOB_OUT: C66.1, U7.30, U7.48, U7.49
T113_X32KIN: U7.25, Y3.1
T113_X32KOUT: U7.24, Y3.2
U9_DRAIN9: R29.2, U9.9
U9_DRAIN13: R32.2, U9.13
U9_DRAIN16: R23.2, U9.16
U9_DRAIN20: R26.2, U9.20
U9_GATE10: Q3.1, U9.10
U9_GATE14: Q4.1, U9.14
U9_GATE17: Q1.1, U9.17
U9_GATE21: Q2.1, U9.21
U9_KSENSA: R35.1, U9.18
U9_KSENSB: R36.1, U9.11
U9_SEN8: R31.2, U9.8
U9_SEN12: R34.2, U9.12
U9_SEN15: R25.2, U9.15
U9_SEN19: R28.2, U9.19
U9_SRC8: Q3.3, R30.1, R31.1
U9_SRC12: Q4.3, R33.1, R34.1
U9_SRC15: Q1.3, R24.1, R25.1
U9_SRC19: Q2.3, R27.1, R28.1
U13_DRAIN16: R37.2, U13.16
U13_GATE17: Q5.1, U13.17
U13_KSENSA: R40.1, U13.18
U13_SEN15: R39.2, U13.15
U13_SRC15: Q5.3, R38.1, R39.1
UART_RX: J7.2, U7.33
UART_TX: J7.1, U7.35
USB_CC1: J12.A5, R50.1
USB_CC2: J12.B5, R51.1
USB_CONN_DM: J12.A7, J12.B7, R49.2
USB_CONN_DP: J12.A6, J12.B6, R48.2
USB_DM: R49.1, U7.114
USB_DP: R48.1, U7.115
USB_VBUS: J12.A4, J12.A9, J12.B4, J12.B9
VBUS_54V: C1.1, C63.1, C65.1, J9.31, J9.32, J9.33, J9.34, J9.35, J9.36, Q1.2, Q2.2, Q3.2, Q4.2, Q5.2, R23.1, R26.1, R29.1, R32.1, R37.1, U9.28, U13.28
VDD_1V2: C14.1, C26.1, C27.1, C28.1, C29.1, C30.1, C31.1, C32.1, C33.1, C34.1, C35.1, C36.1, C37.1, C38.1, C39.1, C40.1, C41.1, C42.1, C43.1, C44.1, C45.1, U1.3, U1.11, U1.14, U1.19, U1.23, U1.30, U1.36, U1.41, U1.45, U1.56, U1.66, U1.70, U1.71, U1.84, U1.87, U1.104, U1.110, U1.114, U1.119, U1.124, U4.5
VDD_1V8: C8.1, C9.1, C16.1, C86.1, C87.1, C88.1, C89.1, U7.20, U7.26, U7.50, U7.89, U12.5
VDD_2V5: C13.1, C17.1, C18.1, C19.1, C20.1, C21.1, C22.1, C23.1, C24.1, C25.1, U1.10, U1.22, U1.33, U1.44, U1.72, U1.83, U1.111, U1.122, U1.128, U3.5
VDD_3V3: C4.1, C12.1, C46.1, C47.1, C48.1, C68.1, C69.1, C70.1, C71.1, C72.1, C73.1, C74.1, C75.1, C76.1, C77.1, C78.1, C79.1, C91.1, C95.1, C96.1, D2.1, J8.4, J9.25, J9.26, J9.27, J9.28, J9.29, J9.30, R6.1, R7.1, R8.1, R9.1, R10.1, R11.1, R13.1, R14.1, R15.1, R16.1, R17.1, R18.1, R19.1, R20.1, R21.1, R22.1, R41.1, R42.1, R44.1, R45.1, R46.1, U1.61, U1.68, U1.99, U3.1, U3.3, U4.1, U4.3, U7.29, U7.34, U7.66, U7.83, U7.128, U8.8, U12.1, U12.3
VDD_3V3_PSE: C62.1, C64.1, C100.1, C101.1, R55.1, U9.1, U9.24, U13.1, U13.23, U13.24, U20.2
VDD_3V3_SB: C97.1, C98.1, C99.1, C102.1, C103.1, C104.1, C105.1, C107.1, C108.1, C109.1, J10.1, R47.1, R52.1, R53.1, R54.1, R56.1, R59.1, R60.1, R61.1, R62.1, R65.1, U10.3, U10.4, U15.3, U16.3, U17.3, U18.2, U19.4, U19.5, U19.6
VDD_5V: C3.1, C5.1, C11.1, J9.19, J9.20, J9.21, J9.22, J9.23, J9.24, R1.1, U11.1, U11.4
VDD_CORE: C6.1, C7.1, C15.1, C80.1, C81.1, C82.1, C83.1, C84.1, C85.1, C90.1, L1.2, R2.1, U7.46, U7.51, U7.81, U7.116, U7.117
VIN_24V: C2.1, C10.1, D54.2, J9.13, J9.14, J9.15, J9.16, J9.17, J9.18, K1.5, U18.3, U20.3

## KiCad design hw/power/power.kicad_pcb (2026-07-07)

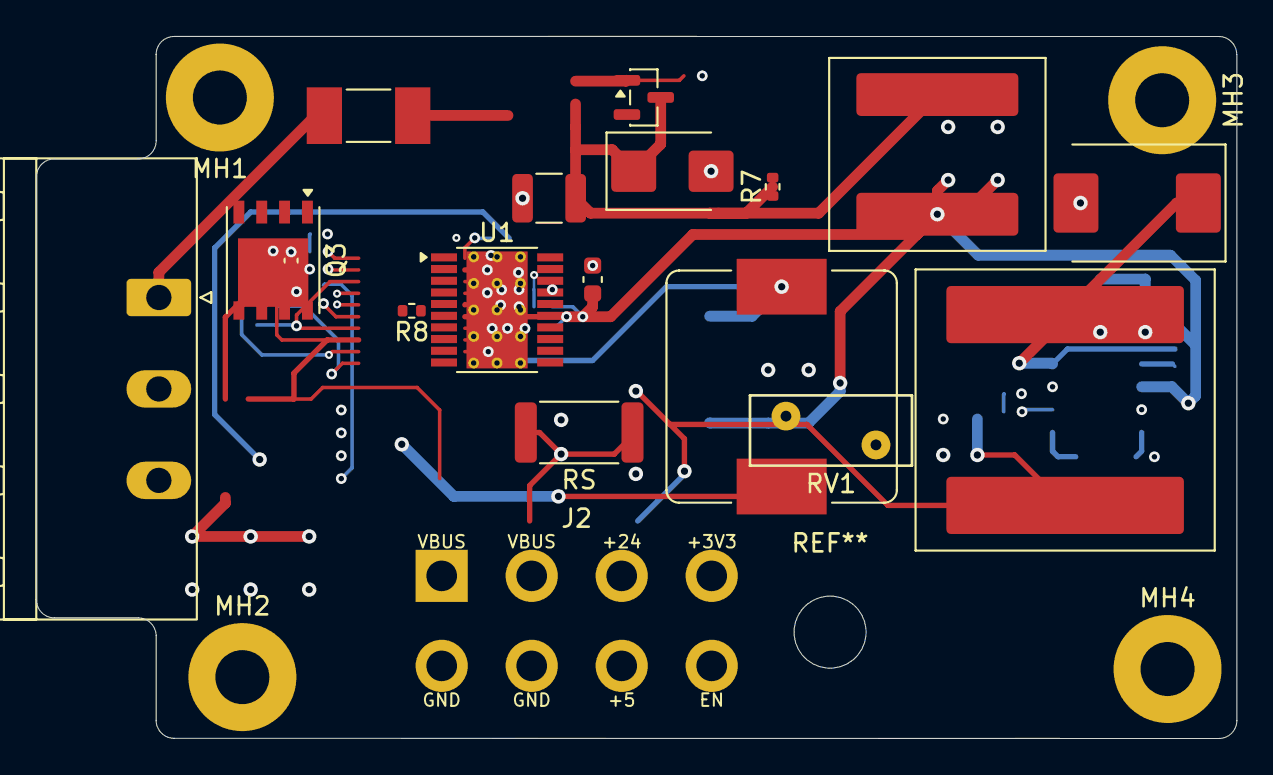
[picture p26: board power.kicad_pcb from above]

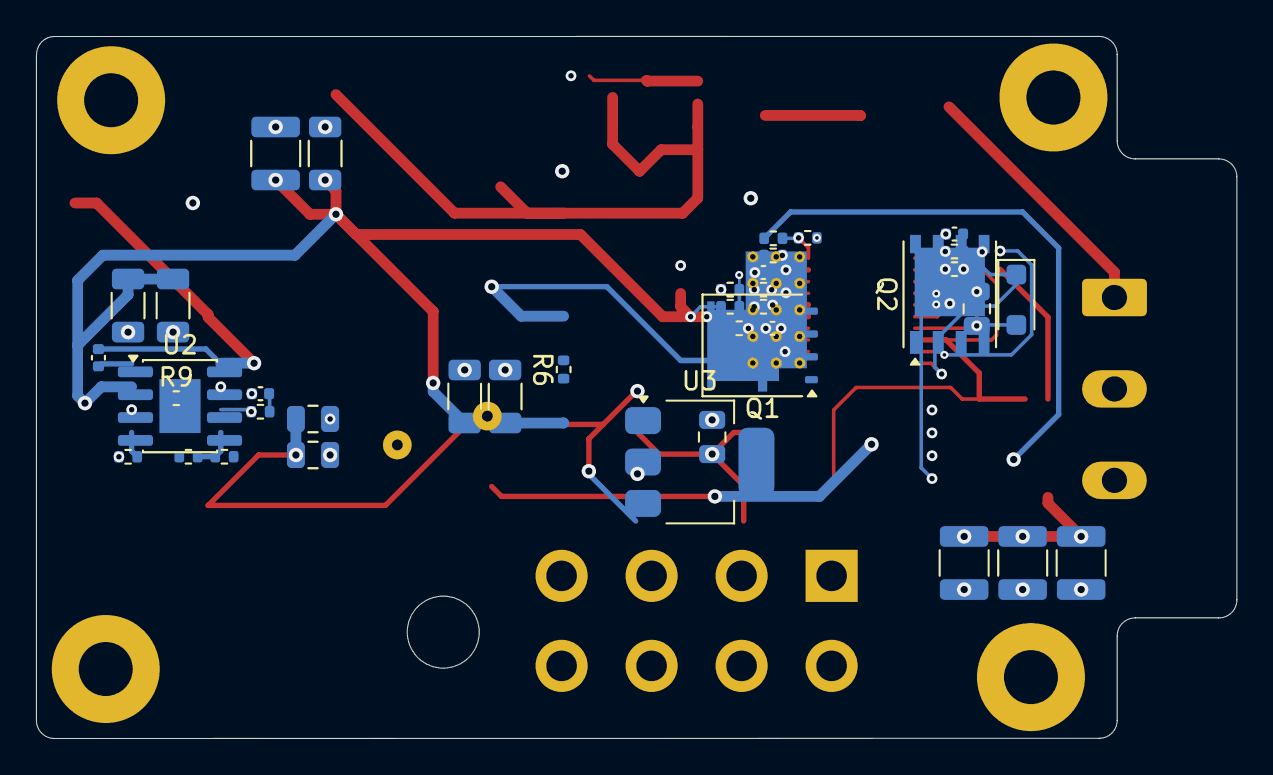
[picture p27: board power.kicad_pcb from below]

Board: 4 copper layers, 66.7 x 39.0 mm, 61 parts (39 on the bottom side), 34 nets.

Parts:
C1, C2: 10uF; C_1210_3225Metric
C3: 100uF; C_1206_3216Metric
C4: 1uF; C_0603_1608Metric
C5: 4.7uF; C_0805_2012Metric
C6, C9, C15: 100nF; C_0402_1005Metric
C7: 10nF; C_0402_1005Metric
C8: 100pF; C_0402_1005Metric
C10, C11, C12: 10uF/100V; C_1210_3225Metric
C13, C14: 22uF/63V; C_1206_3216Metric
C16: 15nF; C_0402_1005Metric
C17, C18: 2.2uF; C_1206_3216Metric
C19, C20: 22uF; C_0805_2012Metric
C21: 10uF; C_0805_2012Metric
D1: SMBJ33A; D_SMB
D2: BZX84C12; SOT-23
D3: SS56; D_SMC
D4: PMEG10010ELR-QX; D_SOD-123F
F1: Fuse_12A_TL_0452012; Fuse_Littelfuse-NANO2-451_453
FB1: 2.2uH XAL1010-222MED Isat34A DCR2.8mR (LCSC C5125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; L_Coilcraft_XAL1010-XXX
J1: MSTB2,5/3-GF-5,08_1776511; PhoenixContact_MSTB_2,5_3-GF-5,08_1x03_P5.08mm_Horizontal_T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
J2: PowerCable_8way; PowerCable_8way_SolderField
L1: 22uH; L_Bourns_SRP1245A
L2: 33uH; L_Coilcraft_XAL1510-333
MH1, MH2, MH3, MH4: MountingHole_M3_PE; MountingHole_3mm_Pad
Q1: SQJ409EP P-ch 40V 7mR (LCSC C727776); PowerPAK_SO-8L_Single
Q2, Q3: BSC057N08NS3G; PowerPAK_SO-8_Single
R1, R2, R13, R15: 100k; R_0402_1005Metric
R3: 6.8k; R_0402_1005Metric
R4: 45.3k; R_0402_1005Metric
R5: 440k; R_0402_1005Metric
R6, R7, R18: 10k; R_0402_1005Metric
R8: 40.2k; R_0402_1005Metric
R9, R10: 100R; R_0402_1005Metric
R11, R12: 2.2R; R_0402_1005Metric
R14: 13k; R_0402_1005Metric
R16: 24.9k; R_0402_1005Metric
R17: 52.3k; R_0402_1005Metric
RS: R_5m_2W; R_2512_6332Metric
RV1: MOV_S14K30_DNP; RV_Disc_D9mm_W3.9mm_P5mm
U1: LM5122; HTSSOP-20-1EP_4.4x6.5mm_P0.65mm_EP3.4x6.5mm_ThermalVias
U2: TPS54560; SOIC-8-1EP_3.9x4.9mm_P1.27mm_EP2.29x3mm
U3: AMS1117-3.3; SOT-223-3_TabPin2

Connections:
BOOST_COMP: R7.1, U1.11
BOOST_COMP_MID: C7.1, R7.2
BOOST_CSN: C8.2, R10.2, U1.3
BOOST_CSP: C8.1, R9.2, U1.4
BOOST_FB: R5.2, R6.1, U1.10
BOOST_HO: R12.1, U1.19
BOOST_LO: R11.1, U1.16
BOOST_RT: R4.1, U1.8
BOOST_SLOPE: R8.1, U1.12
BOOST_SS: C6.1, U1.7
BOOST_SW: C9.2, L1.2, Q2.5, Q3.1, Q3.2, Q3.3, U1.18
BOOST_UVLO: R2.2, R3.1, U1.6
BOOST_VCC: C5.1, D4.2, U1.13, U1.17
BOOT: C15.1, U2.1
BST_BOOST: C9.1, D4.1, U1.20
COMP: R16.1, U2.6
COMP_MID: C16.1, R16.2
FB_5V: R17.2, R18.1, U2.5
GND: C1.2, C2.2, C3.2, C4.2, C5.2, C6.2, C7.2, C10.2, C11.2, C12.2, C13.2, C14.2, C16.2, C17.2, C18.2, C19.2, C20.2, C21.2, D1.2, D3.2, J1.2, J2.5, J2.6, Q2.1, Q2.2, Q2.3, R1.2, R3.2, R4.2, R6.2, R8.2, R14.2, R15.2, R18.2, RV1.2, U1.2, U1.9, U1.14, U1.15, U1.21, U2.7, U2.9, U3.1
L_IN: L1.1, R10.1, RS.2
MAIN_EN: J2.8, R13.2, R14.1, U2.3
PE: J1.3, MH1.1, MH2.1, MH3.1, MH4.1
QH_GATE: Q3.4, R12.2
QL_GATE: Q2.4, R11.2
RP_GATE: D2.1, Q1.4, R1.1
RT_CLK: R15.1, U2.4
SW_NODE: C15.2, D3.1, L2.1, U2.8
VBUS_54V: C10.1, C11.1, C12.1, J2.1, J2.2, Q3.5, R5.1
VDD_3V3: C21.1, J2.4, U3.2
VDD_5V: C19.1, C20.1, J2.7, L2.2, R17.1, U3.3
VIN_24V: C2.1, C3.1, C4.1, C13.1, C14.1, C17.1, C18.1, FB1.2, J2.3, R2.1, R9.1, R13.1, RS.1, U1.5, U2.2
VIN_FUSED: F1.2, Q1.5
VIN_PROT: C1.1, D1.1, D2.3, FB1.1, Q1.1, Q1.2, Q1.3, RV1.1
VIN_RAW: F1.1, J1.1

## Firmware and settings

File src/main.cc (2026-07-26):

/// @file main.cc
/// @brief einheit s5 entry point — single-binary, direct-to-hardware.
///
/// The embedded management-plane wiring: an in-process confd
/// Runtime over S5Backend serves the config lifecycle (configure /
/// set / commit / commit confirmed / rollback), service::
/// HandleProduct serves product reads and operational actions, and
/// the shell reaches both through one InProcTransport — the same
/// Runtime::HandleRequest a standalone daemon would serve. Crash
/// containment mirrors the framework appliance binary: SIGPIPE
/// ignored, fault handlers logging signal + last command +
/// backtrace, and a fork supervisor so a crash never leaves a dead
/// SSH prompt.
///
/// Two modes:
///   (no arguments)  interactive CLI, as above.
///   --apply-boot    oneshot run from init BEFORE login is possible:
///                   build the switch fabric, re-apply the committed
///                   configuration, exit. This is what makes the box
///                   come back as itself after a power cut instead of
///                   as a factory-default switch with its operator's
///                   intent stranded in the commit history.
// Copyright (c) 2026 Einheit Networks

#include <unistd.h>

#include <chrono>
#include <cstdlib>
#include <exception>
#include <filesystem>
#include <format>
#include <fstream>
#include <iostream>
#include <memory>
#include <string>
#include <system_error>

#include "einheit/s5/backend.h"
#include "einheit/s5/fabric.h"
#include "einheit/s5/lldp.h"
#include "einheit/s5/poe.h"
#include "einheit/s5/service.h"
#include "einheit/s5/switch_adapter.h"
#include "einheit/cli/audit.h"
#include "einheit/cli/auth.h"
#include "einheit/cli/command_tree.h"
#include "einheit/cli/confd/runtime.h"
#include "einheit/cli/docs.h"
#include "einheit/cli/globals.h"
#include "einheit/cli/render/terminal_caps.h"
#include "einheit/cli/shell.h"
#include "einheit/cli/signals.h"
#include "einheit/cli/supervisor.h"
#include "einheit/cli/transport/inproc.h"

namespace {

using namespace einheit::cli;

/// Durable state root: /var/lib/einheit/s5 when writable (the
/// setuid launcher runs the CLI as root), else per-user fallback.
/// The confd store, audit log, and crash log all live here so a
/// commit-confirmed window survives a reboot.
auto StateDir() -> std::string {
  const std::string system_dir = "/var/lib/einheit/s5";
  std::error_code ec;
  std::filesystem::create_directories(system_dir, ec);
  if (!ec && ::access(system_dir.c_str(), W_OK) == 0) {
    return system_dir;
  }
  if (const char *home = std::getenv("HOME"); home != nullptr) {
    const auto dir = std::format("{}/.einheit/s5", home);
    std::filesystem::create_directories(dir, ec);
    return dir;
  }
  return std::format("/tmp/einheit-s5-{}",
                     static_cast<long>(::getuid()));
}

/// Shipped factory defaults, read by `load factory`. Part of the
/// image, not of the writable state — a factory reset must not be
/// able to consume a file the operator could have edited into the
/// state directory. Absent from the image means "factory is the empty
/// configuration", which resets the box to its own defaults.
constexpr const char *kFactoryConfigPath =
    "/etc/einheit/s5/factory.conf";

/// Append one audit record to <state_dir>/audit.log. The runtime
/// calls this for every mutating request; it must never throw.
auto MakeAuditSink(const std::string &state_dir) -> audit::Sink {
  const auto path = std::format("{}/audit.log", state_dir);
  return [path](const audit::Record &rec) {
    try {
      std::ofstream f(path, std::ios::app);
      if (!f) return;
      std::string args;
      for (const auto &a : rec.args) {
        args += ' ';
        args += a;
      }
      f << std::format("{} user={} role={} cmd={}{} ok={} {}\n",
                       rec.timestamp, rec.user, rec.role,
                       rec.wire_command.empty() ? rec.command
                                                : rec.wire_command,
                       args, rec.ok ? "yes" : "no", rec.outcome);
    } catch (...) {
      // Auditing must never take the control plane down.
    }
  };
}

/// Runtime options every mode shares, so the interactive CLI and the
/// boot oneshot cannot disagree about where state lives.
auto MakeRuntimeOptions(const std::string &state_dir)
    -> confd::RuntimeOptions {
  confd::RuntimeOptions ropts;
  ropts.state_dir = state_dir;
  ropts.audit = MakeAuditSink(state_dir);
  ropts.factory_config = kFactoryConfigPath;
  return ropts;
}

/// Print the generated operator reference (markdown) and exit.
auto RunDumpDocs() -> int {
  auto schema = einheit::s5::MakeS5Schema();
  auto adapter = einheit::s5::MakeSwitchAdapter(schema);
  CommandTree tree;
  if (auto r = RegisterGlobals(tree, GlobalsOptions{}); !r) {
    std::cerr << std::format("register globals: {}\n",
                             r.error().message);
    return 1;
  }
  for (auto &spec : adapter->Commands()) {
    (void)Register(tree, std::move(spec));
  }
  std::cout << docs::GenerateReference(adapter->Metadata(), tree,
                                       schema.Get());
  return 0;
}

/// Boot-restore oneshot: fabric, then the committed configuration.
/// Ordering is the point — a port or VLAN apply against a box with no
/// bridge either errors out or, worse, succeeds and does nothing.
auto RunApplyBoot() -> int {
  if (!einheit::s5::poe::Init("/dev/i2c-0")) {
    std::cerr << "einheit-s5: warning: PoE I2C bus not available\n";
  }
  auto schema = einheit::s5::MakeS5Schema();
  einheit::s5::S5Backend backend(schema);

  // The fabric is not optional here the way it is in an interactive
  // session: this is the process whose whole job is building it, so a
  // failure has to be loud and non-zero for init to report. Timed and
  // recorded as a boot step either way, so `show system boot` can say
  // which half of the boot went wrong.
  const auto fabric_t0 = std::chrono::steady_clock::now();
  auto fabric_result = backend.EnsureFabric();
  const auto fabric_status =
      einheit::s5::fabric::GetStatus(einheit::s5::fabric::S5Topology());
  confd::BootStep fabric_step;
  fabric_step.name = "fabric";
  fabric_step.ok = fabric_result.has_value();
  fabric_step.duration_ms =
      std::chrono::duration_cast<std::chrono::milliseconds>(
          std::chrono::steady_clock::now() - fabric_t0)
          .count();
  fabric_step.detail =
      fabric_result
          ? std::format("{} up, {} member(s) enslaved",
                        fabric_status.bridge, fabric_status.enslaved.size())
          : fabric_result.error().message;

  const auto state_dir = StateDir();
  einheit::s5::service::SetStateDir(state_dir);
  if (!fabric_result) {
    // Record the failure before giving up, or the one boot an operator
    // most needs explained is the one with no report.
    confd::Runtime runtime(backend, MakeRuntimeOptions(state_dir));
    (void)runtime.ApplyRunningAtBoot({fabric_step});
    std::cerr << std::format("einheit-s5: fabric bootstrap failed: {}\n",
                             fabric_result.error().message);
    return 1;
  }
  std::cout << std::format("einheit-s5: fabric {}\n", fabric_step.detail);
  if (!fabric_status.detached.empty() || !fabric_status.absent.empty()) {
    std::cerr << std::format(
        "einheit-s5: warning: {} detached, {} absent — see "
        "`show fabric`\n",
        fabric_status.detached.size(), fabric_status.absent.size());
  }

  confd::Runtime runtime(backend, MakeRuntimeOptions(state_dir));
  auto restored = runtime.ApplyRunningAtBoot({fabric_step});
  if (!restored) {
    std::cerr << std::format("einheit-s5: boot apply failed: {}\n",
                             restored.error().message);
    return 1;
  }
  if (restored->reverted_pending) {
    std::cout << "einheit-s5: unconfirmed commit-confirmed window "
                 "reverted (boot is the deadline)\n";
  }
  if (restored->seeded_factory) {
    // First boot of a factory-fresh box: the shipped defaults become
    // commit 1. Worth saying out loud — it is the one boot that
    // changes the configuration rather than restoring it.
    std::cout << std::format(
        "einheit-s5: seeded factory defaults as commit {} ({} paths)\n",
        restored->commit, restored->paths);
  } else if (restored->applied) {
    std::cout << std::format(
        "einheit-s5: restored commit {} ({} paths)\n", restored->commit,
        restored->paths);
  } else {
    std::cout << "einheit-s5: no committed configuration to restore\n";
  }
  return 0;
}

auto RunCli() -> int {
  // PoE is optional at runtime (the switch still forwards without
  // it); warn instead of refusing to start.
  if (!einheit::s5::poe::Init("/dev/i2c-0")) {
    std::cerr << "warning: PoE I2C bus not available\n";
  }

  // One schema instance backs both sides: the adapter (completion,
  // client-side validation) and the backend (runtime validation).
  auto schema = einheit::s5::MakeS5Schema();
  auto adapter = einheit::s5::MakeSwitchAdapter(schema);

  const auto state_dir = StateDir();
  // `show system` reads the boot report from here for its
  // config-divergence row.
  einheit::s5::service::SetStateDir(state_dir);
  einheit::s5::S5Backend backend(schema);
  // Best-effort here, unlike --apply-boot: an operator running the CLI
  // unprivileged, or on a dev box with no switch ports, should still
  // get a shell. It matters that this runs before the Runtime is
  // built, because ReadRunning reads VLANs off the bridge.
  if (auto f = backend.EnsureFabric(); !f) {
    std::cerr << std::format("warning: fabric bootstrap: {}\n",
                             f.error().message);
  }
  confd::Runtime runtime(backend, MakeRuntimeOptions(state_dir));
  // A VLAN's name exists only in the configuration — there is nothing
  // on the box to read it back from — so `show vlans` needs a window
  // onto running config to print one.
  einheit::s5::service::SetRunningConfigReader(
      [&runtime]() { return runtime.Running(); });

  CommandTree tree;
  // Core verbs are non-optional; the config verbs are justified
  // here because a real backend holds and applies the candidate.
  if (auto r = RegisterGlobals(tree, GlobalsOptions{}); !r) {
    std::cerr << std::format("register globals: {}\n",
                             r.error().message);
    return 1;
  }
  for (auto &spec : adapter->Commands()) {
    (void)Register(tree, std::move(spec));
  }

  auto caller_result = auth::ResolveLocal();
  auth::CallerIdentity caller;
  if (caller_result) {
    caller = *caller_result;
  } else {
    caller.user = "admin";
    caller.transport = "console";
  }
  // Root gets admin. Everyone else keeps their resolved role.
  if (caller.user == "root") {
    caller.role = RoleGate::AdminOnly;
  }

  // Product commands first, lifecycle commands to the runtime —
  // both behind the one Transport interface the shell knows.
  auto tx = transport::NewInProcTransport(
      [&runtime](const protocol::Request &req) {
        if (auto r = einheit::s5::service::HandleProduct(req)) {
          return *r;
        }
        return runtime.HandleRequest(req);
      });
  if (auto r = tx->Connect(); !r) {
    std::cerr << std::format("transport: {}\n", r.error().message);
    return 1;
  }

  shell::Shell sh;
  sh.tx = std::move(tx);
  sh.adapter = std::move(adapter);
  sh.tree = std::move(tree);
  sh.caps = render::DetectTerminal();
  sh.caller = caller;
  sh.target_name = "local";

  auto result = shell::RunShell(sh);
  // Drop the transport before the runtime goes out of scope: its
  // handler captured the runtime by reference, and the runtime's
  // commit-confirmed timer thread must join while the backend and
  // schema are still alive.
  sh.tx.reset();
  if (!result) {
    std::cerr << std::format("shell error: {}\n",
                             result.error().message);
    return 1;
  }
  return 0;
}

}  // namespace

int main(int argc, char *argv[]) {
  // Contain half of crash safety, installed before anything else
  // can fault: no SIGPIPE kill on peer disconnect, and every
  // SEGV/ABRT/BUS/ILL/FPE is diagnosed (signal + last command +
  // backtrace) then re-raised for a core dump.
  signals::IgnoreSigpipe();
  const auto crash_log = std::format("{}/crash.log", StateDir());
  signals::InstallFaultHandlers(crash_log);

  bool apply_boot = false;
  bool dump_docs = false;
  bool lldp_daemon = false;
  for (int i = 1; i < argc; ++i) {
    const std::string arg = argv[i];
    if (arg == "--apply-boot") {
      apply_boot = true;
    } else if (arg == "--dump-docs") {
      dump_docs = true;
    } else if (arg == "--lldp-daemon") {
      lldp_daemon = true;
    } else if (arg == "--help" || arg == "-h") {
      std::cout << "usage: einheit_s5 [--apply-boot|--dump-docs|"
                   "--lldp-daemon]\n"
                   "  (no arguments)  interactive CLI\n"
                   "  --apply-boot    build the fabric and re-apply the "
                   "committed\n"
                   "                  configuration, then exit (run "
                   "from init)\n"
                   "  --dump-docs     print the generated operator "
                   "reference\n"
                   "                  (markdown) and exit\n"
                   "  --lldp-daemon   run the LLDP transmit/receive "
                   "loop until\n"
                   "                  killed (started by a commit, "
                   "and by init)\n";
      return 0;
    } else {
      std::cerr << std::format(
          "einheit-s5: unknown argument '{}' (try --help)\n", arg);
      return 2;
    }
  }

  if (dump_docs) {
    // Reference docs from the same structures the binary runs on —
    // the repo checks the output in and a test diffs the two, so
    // docs/reference.md cannot go stale (see docs/README.md).
    try {
      return RunDumpDocs();
    } catch (const std::exception &e) {
      std::cerr << std::format("einheit-s5: fatal: {}\n", e.what());
      return 1;
    }
  }

  if (lldp_daemon) {
    // No shell, no supervisor, no config runtime: a long-lived loop on
    // raw sockets that reads its configuration from the file a commit
    // generates. Reconfigured by SIGHUP, stopped by SIGTERM.
    try {
      return einheit::s5::lldp::RunDaemon();
    } catch (const std::exception &e) {
      std::cerr << std::format("einheit-s5: lldp: fatal: {}\n", e.what());
      return 1;
    } catch (...) {
      std::cerr << "einheit-s5: lldp: fatal: unknown error\n";
      return 1;
    }
  }

  if (apply_boot) {
    // No supervisor and no shell: init wants a process that does one
    // thing and reports an exit code.
    try {
      return RunApplyBoot();
    } catch (const std::exception &e) {
      std::cerr << std::format("einheit-s5: fatal: {}\n", e.what());
      return 1;
    } catch (...) {
      std::cerr << "einheit-s5: fatal: unknown error\n";
      return 1;
    }
  }

  // Interactive crash supervision: fork a thin supervisor that
  // re-execs this binary; if the shell dies from a fault signal
  // the parent prints a clear notice naming the last command and
  // the crash log instead of leaving a dead SSH prompt.
  if (std::getenv("EINHEIT_SUPERVISED") == nullptr &&
      ::isatty(STDIN_FILENO) == 1) {
    ::setenv("EINHEIT_SUPERVISED", "1", 1);
    SupervisorOptions sopts;
    sopts.crash_log_path = crash_log;
    return RunSupervised(
        [argv]() -> int {
          ::execv("/proc/self/exe", argv);
          std::perror("einheit-s5: exec (supervisor)");
          return 127;
        },
        sopts);
  }

  // Last net: nothing that escapes the shell may reach
  // std::terminate. Turn it into a clean message + non-zero exit.
  try {
    return RunCli();
  } catch (const std::exception &e) {
    std::cerr << std::format("fatal: {}\n", e.what());
    return 1;
  } catch (...) {
    std::cerr << "fatal: unknown error\n";
    return 1;
  }
}

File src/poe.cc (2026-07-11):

/// @file poe.cc
/// @brief TPS23861 PoE PSE controller — I2C register interface.
///
/// Two TPS23861 ICs on the same I2C bus:
///   U9  (addr 0x20) — ports 1-4
///   U13 (addr 0x28) — port 5 (channel 1 only)
// Copyright (c) 2026 Einheit Networks

#include "einheit/s5/poe.h"

#include <fcntl.h>
#include <linux/i2c-dev.h>
#include <sys/ioctl.h>
#include <unistd.h>

#include <cstdint>
#include <string>
#include <vector>

namespace einheit::s5::poe {
namespace {

constexpr std::uint8_t kAddrU9 = 0x20;
constexpr std::uint8_t kAddrU13 = 0x28;

// TPS23861 register addresses (from datasheet).
constexpr std::uint8_t kRegPowerEnable = 0x19;
constexpr std::uint8_t kRegDetectClass = 0x14;
constexpr std::uint8_t kRegPowerStatus = 0x10;
constexpr std::uint8_t kRegPortCurrent1 = 0x30;
constexpr std::uint8_t kRegPortVoltage1 = 0x32;

int i2c_fd_ = -1;

auto SelectDevice(std::uint8_t addr) -> bool {
  return ioctl(i2c_fd_, I2C_SLAVE, addr) >= 0;
}

auto ReadReg(std::uint8_t addr, std::uint8_t reg)
    -> std::uint8_t {
  if (!SelectDevice(addr)) return 0;
  std::uint8_t val = 0;
  if (write(i2c_fd_, &reg, 1) == 1) {
    read(i2c_fd_, &val, 1);
  }
  return val;
}

auto WriteReg(std::uint8_t addr, std::uint8_t reg,
              std::uint8_t val) -> bool {
  if (!SelectDevice(addr)) return false;
  std::uint8_t buf[2] = {reg, val};
  return write(i2c_fd_, buf, 2) == 2;
}

struct ChipChannel {
  std::uint8_t addr;
  int channel;  // 0-3 within the TPS23861
};

auto MapPort(int port) -> ChipChannel {
  if (port >= 1 && port <= 4) {
    return {kAddrU9, port - 1};
  }
  return {kAddrU13, 0};  // port 5 -> U13 channel 0
}

}  // namespace

auto Init(const std::string &bus) -> bool {
  i2c_fd_ = open(bus.c_str(), O_RDWR);
  return i2c_fd_ >= 0;
}

auto Available() -> bool {
  return i2c_fd_ >= 0;
}

auto GetPortStatus(int port) -> PortPoeStatus {
  PortPoeStatus s;
  s.port = port;

  auto [addr, ch] = MapPort(port);

  auto power_status = ReadReg(addr, kRegPowerStatus);
  s.enabled = (power_status >> (ch * 2)) & 0x01;
  s.delivering = (power_status >> (ch * 2 + 1)) & 0x01;

  // TODO: read actual voltage/current registers and scale
  // per TPS23861 datasheet formulas. These are placeholder
  // reads that need the real register map + scaling.
  s.voltage_v = 0.0;
  s.current_ma = 0.0;
  s.power_w = 0.0;
  s.status = s.delivering ? "delivering" :
             s.enabled ? "searching" : "disabled";
  s.classification = "unknown";

  return s;
}

auto GetAllStatus() -> std::vector<PortPoeStatus> {
  std::vector<PortPoeStatus> result;
  for (int p = 1; p <= 5; ++p) {
    result.push_back(GetPortStatus(p));
  }
  return result;
}

auto SetPortEnabled(int port, bool enabled) -> bool {
  auto [addr, ch] = MapPort(port);
  auto val = ReadReg(addr, kRegPowerEnable);
  if (enabled) {
    val |= (1 << ch);
  } else {
    val &= ~(1 << ch);
  }
  return WriteReg(addr, kRegPowerEnable, val);
}

auto SetPowerLimit(int port, std::uint32_t limit_mw) -> bool {
  // TODO: implement per TPS23861 power management registers.
  (void)port;
  (void)limit_mw;
  return false;
}

auto ResetPort(int port) -> bool {
  if (!SetPortEnabled(port, false)) return false;
  usleep(500000);  // 500ms power-off
  return SetPortEnabled(port, true);
}

auto GetTotalPower() -> double {
  double total = 0.0;
  for (int p = 1; p <= 5; ++p) {
    total += GetPortStatus(p).power_w;
  }
  return total;
}

}  // namespace einheit::s5::poe

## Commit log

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2026-06-29 Port f.appliance netlist to s105 switch hardware
    KSZ9477 + 5 GbE MagJacks + power tree + SPI management reused
    verbatim from f.appliance. Dropped firewall-specific LAN7431 NIC,
    PCIe FPC, Cubie A7S mount, USB-C PD. Added V3c management SoC,
    SPI NAND flash, RMII CPU-port link, barrel-jack power, UART console.
    SkiDL script generates 174 components, 0 errors. V3c pin numbers are
    explicit placeholders (P_xxx) pending the datasheet — net wiring is
    complete and correct, only V3c-side pin assignments need the real
    pinout. Deliberately not invented.
    [HR911130A.step]
2026-06-30 Switch management SoC from V3c to Allwinner T113-S3
    Replace V3c placeholder pins with real T113-S3 ball numbers from
    datasheet v1.6. T113-S3 (eLQFP128, SiP 128MB DDR3) provides RGMII
    on the PG bank -> KSZ9477 port 6 (MAC-to-MAC, no magnetics), freeing
    all 5 copper PHYs for users. Adds 0.9V core buck + 1.8V DRAM LDO.
    Netlist generates with 0 errors.
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2026-06-30 Replace discrete magnetics with LPJG0926HENL PoE+ magjack
    Swap the per-port YDS 30F-51NL transformer + Amphenol RJHSE5380
    plain jack + discrete LEDs for a single LPJG0926HENL PoE+ GbE
    magjack per port. Integrated magnetics, green/yellow LEDs, and
    exposed line-side center taps (VC1-VC4) for PSE power injection.
    Saves 5 transformers + 10 LEDs + passives (211 -> 191 components).
    PoE Mode A: VC1+VC2 -> 48V from TPS23861, VC3+VC4 -> GND return.
    Also: move KiCad project from board/ to hw/, add T113-S3 eLQFP128
    footprint with exposed pad (pin 129 -> GND), add 48V terminal block
    (Phoenix MKDS 5.08mm).
    [LPJG0926HENL.step, s5.kicad_pcb]
2026-07-01 Barrel jack, drop BOOT button, 256MB NAND flash, net classes
    - Power input: terminal block -> 5.5/2.5mm barrel jack (48V Meanwell)
    - Remove SW1 (FEL/boot button), keep only reset (SW2)
    - Flash: W25Q128 SPI NOR (16MB) -> W25N02 SPI NAND (256MB) for
    full einheit stack + web UI
    - Net classes: MDI (0.12mm/0.15mm clearance), RGMII, POWER with
    auto-assignment patterns; via sizes 0.3/0.45/0.6/0.8mm
    - Track widths reduced to 0.12mm for KSZ9477 QFP escape (0.4mm pitch)
    [s5.kicad_pcb]
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2026-07-01 Micro SD slot, MSTB power connector, fault LED
    - Replace eMMC B2B connector with micro SD slot (Molex 104031-0811)
    on T113 SDC0 (PF bank, 4-bit). Standard part, JLCPCB-assemblable.
    - Power connector: Phoenix Contact MSTB 2,5/3-GF-5,08 (5.08mm,
    horizontal, threaded flange). Mates with MSTB 2,5/3-ST-5,08.
    3-pin: +24V / GND / PE.
    - Fault/alarm LED (red) on T113 GPIO PE4.
    - Target enclosure: ~105mm W x 90mm H x 60mm D for DIN-rail mount.
2026-07-01 Add S5 switch adapter with PoE control, fix USB-C footprint
    Software:
    - Scaffold einheit-cli switch adapter from s100, ported to s5
    namespace with KSZ9477 DSA + TPS23861 PoE I2C control.
    - Commands: show interfaces/counters/vlans/mac-table/poe/system,
    set poe enable/disable/reset, set hostname/ip/dns/ntp/user,
    shell, ping, traceroute, reboot.
    - poe.cc: TPS23861 I2C driver skeleton — U9 (0x20, ports 1-4),
    U13 (0x28, port 5). Register map TODOs for voltage/current
    scaling.
    - Builds and runs on host (0 errors, PoE gracefully degrades
    when I2C bus unavailable).
    Hardware:
    - Fix USB-C footprint: remove overlapping pads (A1/B12, A4/B9,
    A9/B4, A12/B1 merged), local copy in connector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
    [s5.kicad_pcb]
2026-07-01 ARM cross-compile toolchain, fix boost converter orphan nets
    - Add cmake/arm-linux-gnueabihf.cmake for Cortex-A7 targets
    (T113/T153). Static-linked ARM binary: 3.2MB.
    - Fix duplicate Net() calls in LM5122 boost section that created
    disconnected orphan nets (BOOST_SS, BOOST_VCC, BOOST_RT,
    BOOST_ILIM, BOOST_PG).
2026-07-02 Add T153 dev-board deploy docs, fix boost orphan nets
    - deploy/t153-dev-setup.md: document the stock-image setup, clean
    separation under /mnt/UDISK/einheit/, reset path, and the /home
    700->755 sshd pubkey gotcha (production image must ship /home 755).
    - Login model: root->bash, admin/oper->CLI auto-launch.
    - Fix remaining duplicate Net() calls in LM5122 boost section.
2026-07-02 Add setuid-root CLI launcher (privilege model)
    einheit-launch: tiny plain-C setuid-root launcher that authenticates
    the caller by uid, whitelists root/admin/oper, sets EINHEIT_USER/ROLE,
    scrubs the environment, and execs the CLI. Admin becomes root (set
    commands work); operator drops to unprivileged (read-only, set/shell
    gated by role) — defence in depth. Verified on the T153: admin
    set-hostname changes the OS hostname, operator is blocked.
    deploy doc: full privilege model + the dev-board gotchas found while
    bringing the CLI up on real hardware (/dev/null 660->666, /home 700->
    755, umask-077 einheit perms, ping_group_range + iputils for
    unprivileged ping). All must be handled correctly in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
2026-07-02 Harden s5 adapter against bad input; top-level exception net
    - Replace unguarded std::stoi in the PoE and show-log handlers with
    a non-throwing ParseInt/ParsePort (strtol-based, range-checked).
    Bad input now renders "invalid port (expected 1-5)" / "invalid
    line count" instead of throwing.
    - main(): wrap RunShell in try/catch as a last-resort net so nothing
    can reach std::terminate (silent abort) — turns any escapee into a
    clean "fatal:" message + non-zero exit.
    [main.cc]
2026-07-02 Fix segfault: initialize adapter schema_ (was null)
    The real cause of the "typing `set ` crashes/closes the session" bug:
    SetSchema() was never called, so schema_ was a null shared_ptr, and
    GetSchema() returned *schema_ — a null dereference. Typing `set ` at
    the prompt routes tab-completion through schema::Completions(
    GetSchema(), ...), which segfaulted. A SIGSEGV, not a C++ exception,
    which is why the try/catch guards didn't stop it.
    Initialize schema_ to an empty Schema in the constructor so GetSchema
    never derefs null. Verified with a pty harness driving `set <TAB>`:
    process now exits signal 0 (was SIGSEGV).
    NOTE: s100 has the identical latent bug (schema_ never set) — fix
    there to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
2026-07-04 hw: normalize vendor 3D models, self-contained vendor-3d/, KiCad 10 migration
    - All connector/chip STEP models rotated upright and origin-corrected
    - Custom models moved to vendor-3d/ with ${KIPRJMOD} paths (portable)
    - Board opened/saved in KiCad 10; pre-10 backup kept as s5.kicad_pcb.bak-pre-k10
    [2171820001.step, Crystal_SMD_2016-4Pin_2.0x1.6mm.step, HFD23_box.step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]
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2026-07-06 hw: split into digital/ + power/ boards; add hardened power board
    Reorganize hw/ so both boards live under it: hw/digital/ (T113+KSZ+PSE) and
    hw/power/ (new separate PoE power board). The power board isolates all the
    switching (input + LM5122 boost 24V->54V + TPS54560 buck 5V + AMS1117 3V3)
    onto its own module for cert/EMC reuse, connected via a Molex Micro-Fit 3.0
    2x6 right-angle interconnect.
    The power circuits were lifted from digital/netlistscript and then verified
    part-by-part against datasheets -- which surfaced ~a dozen real defects in the
    original design (all fixed on the power board):
    - LM5122: entirely wrong pinout (phantom DEMB/ILIM/EN/PG pins) + wrong package
    (QFN vs HTSSOP) +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
    [2171820001.step, Crystal_SMD_2016-4Pin_2.0x1.6mm.step, HFD23_box.step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]
2026-07-06 hw/power: real part selection, OPT-pin fix, drop PWR_GOOD, name gate nets
    Datasheet-verified part selection (real, LCSC-stockable):
    - Reverse-pol P-FET: Vishay SQJ409EP (40V, 7mR, PowerPAK SO-8L, C727776)
    - Fuse: Littelfuse 0452012 Nano2 Slo-Blo 12A (was placeholder 10A)
    - Input inductor FB1: Coilcraft XAL1010-222MED (2.2uH, Isat 34A, C5125746)
    - Buck inductor: Coilcraft XAL1510-333 (33uH, Isat 16.7A, C3911775)
    - Boost bootstrap diode: Nexperia PMEG10010ELR-QX (100V, SOD-123W, C5361358)
    Bug fix: LM5122 OPT pin was tied to VCC (Master2 = needs external clock, would
    NOT free-run standalone). Corrected to AGND (Master1, free-running from RT) per
    SNVS954H Table 1 / Fig 32. Confirmed RT=45.3k ->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
2026-07-06 hw/core: fix T113/TLV62569 power bugs; split switching to power board
    Datasheet audit of every core-board IC (KSZ9477, TPS23861 x2,
    W25N02JW, STM32G071, T113-S3) found two chip-destroying bugs. The
    digital/logic pins were all transcribed correctly; the failures were
    localized to power, matching the power-board pattern.
    T113-S3 rail voltages (128-ball pin map was correct -- only the rail
    grouping was wrong):
    - VDD-SYS0/1/2 were on 3.3V but are a 0.9V core rail (3.7x over) ->
    moved to VDD_CORE
    - VCC-PLL/RTC/AVCC were on 3.3V but are 1.8V -> VDD_1V8
    - VCC-DRAM0/1 were on 1.8V but DDR3 I/O is 1.5V -> internal LDOB-OUT
    Ref: T113-S3 datasheet v1.6 Table 5-2.
    TLV62569 0.9V core buck: fabricated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
2026-07-07 s5 power: localize vendor footprints so re-import keeps 3D models
    L1 (SRP1245A), Q1/Q2/Q3 (PowerPAK SO-8/8L) and F1 (NANO2 fuse) used
    stock footprints whose 3D models ship with neither KiCad 9 nor 10, so
    the models resolved to nonexistent files and were silently dropped
    from the kicad-cli STEP export. Direct model-path edits in the .pcb
    did not survive because "Update PCB from Netlist" re-reads each
    footprint from its library (stock path).
    Fix: copy the four footprints into the project power.pretty lib with
    the ${KIPRJMOD}/vendor-3d/*.step model baked in, and point the netlist
    at power:<name>. Now a netlist re-import brings the correct local
    model every time. Verified: STEP export embeds al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
2026-07-07 s5 power: fix L1 orientation and restore model colors
    Two regressions from the previous normalization commit:
    - L1 (SRP1245A) came out upside down: a bounding box can't tell which
    face carries the terminals, and the auto-picked X-rotation sign put
    the wrong side down. Flipped it (rotX -90 instead of +90).
    - All four models rendered flat gray: wrapping the solids in a fresh
    Compound to satisfy build123d's STEP writer stripped the per-face
    STEP colors.
    Redone via OCP XCAF: capture each solid/face colour before the rigid
    transform, move the shape sharing topology (copy=False), then re-apply
    the colours face-by-face. Colour retention now 17/18, 21/22, 7/8, 3/4
    styled-items (the missing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
    [Fuse_Littelfuse_0452012.step, L_Bourns_SRP1245A.step, PowerPAK_SO-8.step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]
2026-07-07 s5 power: point board 3D models at local vendor-3d files
    Repoint L1/Q1/Q2/Q3/F1 model paths in the board to
    ${KIPRJMOD}/vendor-3d/*.step so the STEP export embeds them without a
    netlist re-import. (A re-import will swap these footprints to the
    project power.pretty copies committed in c265e82, which carry the same
    paths.) Also includes KiCad's own footprint reordering from the last
    edit session.
    [power.kicad_pcb]
2026-07-07 s5 core: fix light-guide model facing the wrong way
    The Mentor 1278.1004 STEP had its LED/back end at high Y and pipes
    pointing -Y, so it rendered reversed -- pipes aiming back over the
    board instead of out to the panel. Rotated 180 deg about Z and aligned
    the press-in lugs to the footprint holes (0, 3.8); pipes now point +Y,
    width centred, height (Z, lugs into board) unchanged. Colour preserved
    (pale blue clear plastic). Baked into the STEP, so the footprint and
    board offset drop from -4.7 to 0. Raw download kept as *.step.orig.
    [Mentor_1278.1004.step, s5.kicad_pcb]
2026-07-07 s5: mounting holes M3 -> M2.5 (both boards)
    The enclosure PCB bosses are tapped M2.5, so the board mounting holes
    must clear M2.5, not M3. Both boards are coplanar and screw into the
    same bosses, so change both. New project footprint
    MountingHole_2.7mm_M2.5_6mmPad: 2.7mm drill (M2.5 clearance) but keeps
    the 6mm plated pad (the stock M2.5 pad is only 5.4mm) to match the
    6mm boss OD and stay PE-bonded (zone_connect). MH1-4 on each board
    still tie to PE. Re-import the netlist on each board to apply.
2026-07-07 s5 core: correct light-guide orientation (undo erroneous 180 flip)
    The prior fix (082eb89) seated the lugs correctly but added a spurious
    180 deg Z rotation, leaving the pipes pointing back over the board.
    The downloaded model's front/back was already correct — it only needed
    translating to seat the lugs at (0,3.8). Redone as translate-only from
    the pristine .orig: pipes now reach the footprint front face (Y+8.1),
    lugs seated, height unchanged, pale-blue colour preserved.
    [Mentor_1278.1004.step]
2026-07-07 s5 core: flip light-guide model 180 (pipes to other end)
    Per repeated on-screen feedback: rotate the model 180 about the lug
    axis so the pipes face the opposite way. Lugs stay seated in the drill
    holes (0,3.8), height and pale-blue colour preserved.
    [Mentor_1278.1004.step]
2026-07-07 s5 core: revert light-guide flip (LEDs back on pads)
    The 180 flip pulled the LED cavities off the LED pads. LEDs belong at
    Y=0 over the pads; pipes are then necessarily on the far end (Y=8.1).
    Restore translate-only orientation.
    [Mentor_1278.1004.step]
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2026-07-08 s5: replace cable interconnect with Samtec PowerStrip (coplanar, no cable)
    Drop the Mini-Fit Jr header + 8-way solder-field cable entirely in favour
    of a Samtec PowerStrip MP right-angle board-to-board pair that mates the
    two boards coplanar, edge-to-edge:
    - Core J9 = MPT-06-01-...-RA terminal (male blades)
    - Power J2 = MPS-06-01-01-L-RA socket (female, recessed -- goes on the
    energized source board so no exposed live contacts when unmated)
    6 positions, each a 20A+ dual-blade landed on 6 paralleled THT pins
    (36 holes/side). Boards face each other so MPT blade N mates MPS pos N;
    net map VBUS/GND/VIN_24V/VDD_5V/VDD_3V3/MAIN_EN verified identical and
    correctly mating across both sides. Foot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
    [MPS-06-01-RA.step, MPT-06-01-RA.step]
2026-07-08 s5: fix Samtec connector 3D model orientation (were upside down)
    The Samtec PARTserver STEP models imported pins-up / body-below-board.
    Re-seated both by aligning the model pins to the footprint pads
    (deterministic: 180 about X to point pins down, +180 about Z to match
    the footprint's body direction, then translate pins onto the pad
    centroid, tips ~2mm below the board). Now pins go down into the board,
    body sits on top, mating face faces the edge -- correct for the STEP
    export / enclosure model. Raw downloads kept as *.step.orig.
    [MPS-06-01-RA.step, MPT-06-01-RA.step]
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2026-07-08 s5 power: bake MPS connector model orientation into library footprint
    Model rotate (90,0,0) + offset (0,6.8,8.0) -- the values that seat it
    correctly, set on the library footprint so re-import keeps them instead
    of reverting to the raw PARTserver orientation.
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2026-07-09 s5: swap MAIN_EN and VBUS_54V on the board-to-board connector
    Blade/position 1 = MAIN_EN, 6 = VBUS_54V (was reversed) on both the
    core MPT (J9) and power MPS (J2) so they still mate pin-for-pin.
2026-07-10 Migrate s5 CLI to the confd/engine management plane
    Adopt the framework's embedded single-binary model: an in-process
    confd Runtime over a real ConfigBackend serves the config
    lifecycle, the same Runtime::HandleRequest a standalone daemon
    would serve (gaps #1/#3).
    - backend.{h,cc}: S5Backend implements confd::ConfigBackend. The
    schema is baked in-code via LoadSchemaFromString (hostname,
    interfaces.<if>.address|dhcp, dns, ntp, ports.<n>.enabled,
    poe.<1-5>.enabled|power_limit_mw). Apply validates the whole
    candidate before touching hardware, then programs DSA / TPS23861
    / system state in deterministic order; HardwareRejected vs
    PartialApply so a failed commit never advances runnin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
    [main.cc]
2026-07-11 backend: don't seed or apply poe.* paths when the PoE bus is absent
    Found running the CLI on a PoE-less VM: ReadRunning seeded
    poe.N.enabled=false with no I2C bus, so every commit re-applied
    phantom PoE values and died mid-apply (PartialApply) after the
    hostname/DNS writes had already hit the box.
    - poe::Available(): whether Init found the bus.
    - ReadRunning skips poe paths when the bus is absent.
    - BuildPlan rejects poe.* candidates as ValidationFailed before any
    write, so a PoE-less box never half-applies.
    Verified on a Debian VM clone (takt s5-test): commit, rollback
    previous across process restart, and commit-confirmed auto-revert
    on startup recovery (session death → expired window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
    [poe.cc, poe.h]
2026-07-11 s5: rewrite README to match reality (was a stale 'no code yet' charter)
    The charter claimed no code and omitted PoE entirely. Reality:
    - 5-port managed switch WITH PoE PSE (2x TPS23861, all 5 ports)
    - industrial 24V DC in -> LM5122 boost -> 54V PoE bus (not '48V in')
    - two-board design (core + power) joined by Samtec PowerStrip interconnect
    - flash resolved to SPI NAND W25N02JW (not the NOR-vs-NAND open decision)
    - software v0.1.0 building (switch adapter/DSA, backend/service, PoE, confd)
    - both boards placed AND essentially routed (core ~2000 tracks/500 vias,
    power via copper pours) -- DRC + fab-prep next
    Resolved decisions marked; remaining open items = the in-script hw TODOs.
2026-07-11 s5-core: add cap placement guide (where every decoupling/bulk cap goes)
    Mirror the power board's CAP_PLACEMENT.md for the core board. Maps all ~110
    caps to their location by net + IC, from netlistscript: interconnect entry
    bulk (J9 blades, 54V=100V part), the 4 point-of-load converters (in/out tight,
    0.9V buck loop first), KSZ9477 decoupling (20x1.2 / 9x2.5 / 3x3.3, one per
    pin), T113 decoupling (12x3.3 / 6x core / 4x1.8, one per pin + the 0.9V VDD-SYS
    and 1.8V analog gotchas), TPS23861 VDD/VPWR, and the 5x magjack center-tap
    caps. Key rule stated: decouple(rail,N) = one cap per power pin, not clustered.
2026-07-11 s5-core: add standard SMD footprint libs to project fp-lib-table
    Same gap as m_rk3566: the core project fp-lib-table only had the project libs
    (connectors, chips), so re-import errored 'Capacitor/Resistor... not found' for
    the standard footprints. Added the 16 standard libs the netlist uses (Cap/Res/
    Diode/Crystal/Inductor/Package_*/Connector_*/Button/Sensor) pointing at
    /usr/local/share/kicad/footprints. Project libs preserved.
2026-07-11 s5-power: add standard SMD footprint libs to project fp-lib-table
    Same gap as core: power fp-lib-table only had the 'power' project lib. Added
    the 8 standard libs its netlist uses (Capacitor/Resistor/Diode/Inductor/
    Package_SO/Package_TO_SOT_SMD/Connector_Phoenix_MSTB/Varistor). Prevents the
    footprint-not-found errors on the power board's next re-import.
2026-07-11 s5-core: name every cap in CAP_PLACEMENT.md by refdes + verified value
    The guide grouped caps by IC but didn't say which refdes go where. Now every
    cap C1-C110 is listed under its rail with its actual value (pulled from
    netlist_s5.net, not asserted): KSZ 1.2V = C26-C45, T113 core = C80-C85, etc.
    Caught two placement facts in the process: C90 is a 0.9V core bulk (not 3.3V),
    and C63/C65 are 100nF sitting on the 54V VPWR rail so they must be >=100V.
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2026-07-11 s5-core: cap placement + routing progress; clear solder-mask bloat
    Placed the remaining decoupling/bulk caps (one-per-pin per CAP_PLACEMENT.md) and
    continued routing. Also cleared the easyeda 0.102mm solder_mask_margin bloat on
    all 350 placed pads (KSZ U1 + magjacks J2-J6 + USB-C J12 + Phoenix J9) -> 0,
    fixing the 'mask aperture bridges different nets' DRC errors on the KSZ.
    [s5.kicad_pcb]
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2026-07-12 s5-power: JLC assembly BOM CSV (LCSC by C#, bypasses KiCad field import)
    The re-import doesn't carry the netlist's custom LCSC fields onto the board, so
    the Fabrication Toolkit BOM came out blank on LCSC and JLC fuzzy-matched by MPN
    (worked for clean names, failed on LM5122 + inductors). This CSV is generated
    straight from the netlist: 11 named parts with verified C# (U1 LM5122 C77241,
    FB1 C5125746, L2 C3911775, the ICs/FETs/diodes), jellybean R/C blank for JLC
    Basic value-match, hand-add parts (F1/J1/J2/L1/RV1/RS/MH) excluded. Also added
    L2 C3911775 to the netlist LCSC dict.
    [bom_s5power_jlc.csv]
2026-07-12 s5-power: BOM covers all 61 designators (fix JLC 'designators missing')
    JLC compares the BOM against the CPL and rejects any placed designator not in
    the BOM. v1 excluded the hand-add parts (and my regex dropped the no-digit ref
    RS), and the mounting holes lack exclude_from_pos_files so they're in the CPL
    too. Now the BOM lists every placed part: 11 named w/ verified LCSC, jellybeans
    blank for Basic match, hand-add + MH blank -> mark Do Not Place in the JLC UI.
    [bom_s5power_jlc.csv]
2026-07-12 s5-power: fix unbuildable 22uF/63V input caps -> 10uF/100V/1210
    22uF/63V doesn't exist in 1206 (63V MLCC tops out ~4.7uF there) -- that's why
    JLC couldn't match C13/C14. Swapped the 2x 24V-input bulk caps for 3x
    10uF/100V/1210 (C49326812, the same part as the 54V-bus caps C10-C12): more
    voltage margin, and at 24V bias 10uF/100V derates far less than a 22uF/63V, so
    3x holds comparable effective bulk. All six 10uF/100V now carry the LCSC field.
    BOM regenerated (adds C15; C13/C14 change 1206->1210 -> re-import in the power
    redo).
    [bom_s5power_jlc.csv]
2026-07-12 s5-power: bulk caps -> deep-stock parts (10uF/100V ceramic is unsourceable)
    C49326812 (10uF/100V/1210) is stock-short and there's no deep-stock 10uF/100V
    ceramic anywhere -- same high-CV trap as 22uF/63V. Went all-ceramic (longevity;
    no aluminum-elec on an always-on rail):
    - 54V bus: 5x 4.7uF/100V/1210 C337978 (~23uF)
    - 24V input: 3x 10uF/63V/1210 C6120029 (~11.6k stock; 63V is enough, never
    needed 100V there)
    Same 1210 footprint, verified stock. BOM regenerated.
    [bom_s5power_jlc.csv]
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2026-07-26 s5: build the switch fabric, and boot into the committed config
    The product half of ROADMAP Phase 0. An s5 could not previously survive
    a reboot: nothing re-applied committed config at startup, and the bridge
    every port and VLAN apply depends on was hand-built by a test prep
    script, so the product could not construct its own switch.
    Fabric bootstrap (WP0.2). New fabric.{h,cc} owns the topology — br0 with
    vlan_filtering, lan1..lan4 enslaved, lan5 left routed as the uplink
    Phase 2/3 need for WAN, and the DSA conduit up. Hardcoded rather than a
    `fabric.*` schema root: on a five-port box with one ASIC there is
    nothing here an operator can usefully change, and a schema would only
    invite config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
    [CPPLINT.cfg]
2026-07-26 s5: port parameters, static MACs, IGMP snooping, counters
    The VM-provable subset of ROADMAP Phase 1 (WP1.1, 1.4, 1.7, 1.8), plus
    the product side of the Phase 0 boot report and divergence alarm.
    Bench-gated packages (RSTP, mirroring, storm control, PoE priority) are
    out of this round.
    Boot report + divergence. `--apply-boot` now times its fabric bootstrap
    and hands it to the runtime as a boot step, so `show system boot` can
    say which half of a bad boot went wrong; the failure path records the
    step before giving up, because the one boot an operator most needs
    explained is the one that failed. `show system` gains a
    config-divergence row with three distinguishable answers — none, N paths
    div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
    [main.cc]
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
